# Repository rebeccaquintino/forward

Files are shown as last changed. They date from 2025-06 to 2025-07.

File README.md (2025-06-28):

# Forward Converter

This project implements a **Forward Converter** with three windings, designed for Power Electronics II course in UFSC.

## 📐 Technical Specifications

- **Topology**: Isolated Forward Converter with 3 windings
- **Input (VIN)**: 100V DC
- **Output (VOUT)**: 12.5V DC
- **Switching Device**: IRQ740
- **Diodes**: MUR840
- **Input Capacitor**: 4.7µF @ 250V
- **Output Inductor**: 500µH
- **Transformer**: Handmade three-winding transformer
- **Switching Frequency**: 30k Hz

## 📦 Project Contents

- Electrical schematic (`.SchDoc`)
- PCB layout (`.PcbDoc`)
- Custom libraries (`.SchLib`, `.PcbLib`)
- Draftsman documentation (`.PCBDwf`)

## 🙋‍♀️ Authors

Developed by **Rebecca Quintino do Ó** and **Felipe Pastana**  
As part of the Power Electronics II course – UFSC  
[GitHub Repository](https://github.com/rebeccaquintino/forward)

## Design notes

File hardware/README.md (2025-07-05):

# Forward Converter Hardware Design

This folder contains all the necessary files and documentation related to the hardware design and implementation of the Forward Converter project.

## Folder Structure:

* **`_Previews/`**: Contains various preview images, renderings, or snapshots of the PCB layout, 3D models, or other hardware aspects.
* **`fabrication/`**: Includes all the final files required for manufacturing the Printed Circuit Board (PCB), such as Gerber files, drill files, pick-and-place files, and bill of materials (BOM).
* **`History/`**: Stores previous versions or snapshots of the hardware design files, allowing for tracking changes and reverting to earlier states.
* **`libraries/`**: Contains custom or project-specific component libraries (e.g., Altium libraries for footprints, 3D models, and schematic symbols) used in the PCB design.
* **`outputs/`**: Contains generated output files from the PCB design software, such as PDFs of schematics, assembly drawings, or other production-ready documentation.
* **`source/`**: Holds the primary source files for the hardware design, including the main Altium Designer project files (e.g., schematics and PCB layout).
    * `Forward_Project.PrjPcb`: The main Altium Designer PCB project file.
    * `Forward_Project.PrjPcbStructure`: Related project structure file for Altium Designer.

---

**Note:** This README provides an overview of the hardware design files. For detailed information on the circuit operation, component selection, and design rationale, please refer to the project's main documentation.

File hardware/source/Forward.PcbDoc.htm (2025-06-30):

Reporting Options

# File in Newer Format

Date | : | 29/06/2025
Time | : | 21:51:18
Filename | : | C:\Users\rebec\Desktop\faculdade\optativas\elepot2\forward\hardware\Forward.PcbDoc

Version | Warning
Release 24.4 | CAUTION - This PCB document contains polygon pours with the "Obey Rules" option enabled. If you save the PCB document in this older version, the "Obey Rules" option will be turned off for these polygon pours.

This file was generated by a later version of the software

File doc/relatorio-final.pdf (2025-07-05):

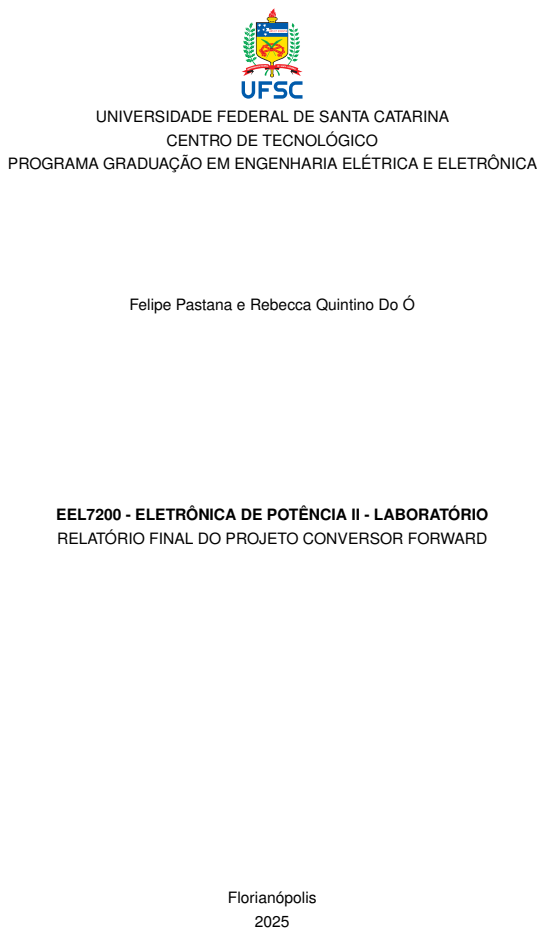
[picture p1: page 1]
Florianópolis

UNIVERSIDADE FEDERAL DE SANTA CATARINA

CENTRO DE TECNOLÓGICO

PROGRAMA GRADUAÇÃO EM ENGENHARIA ELÉTRICA E ELETRÔNICA

Felipe Pastana e Rebecca Quintino Do Ó

EEL7200 - ELETRÔNICA DE POTÊNCIA II - LABORATÓRIO
RELATÓRIO FINAL DO PROJETO CONVERSOR FORWARD

1

### 1 INTRODUÇÃO

Neste trabalho, serão apresentadas as especificações e etapas de projeto teórico e prático para a construção de um conversor do tipo Forward. O trabalho envolve os conhecimentos adquiridos durante toda a disciplina, como cálculos teóricos para a definição dos valores dos componentes, projeto de magnéticos, escolha de componentes, cálculos térmicos, escolha de dissipadores e, por fim, uma análise de perdas e de rendimento do conversor

2

### 2 ESPECIFICAÇÃO DO PROJETO

As especificações do projeto do conversor Forward são apresentadas a seguir:
- Tensão de alimentação da fonte antes do conversor (Vin): 100 V
- Tensão desejada na saída do conversor (Vo): 12,5 V
- Potência desejada na saída do conversor (Po): 50 W
- Frequência de comutação do conversor (fs): 30kHz - 50kHz
- Ondulação da corrente nos indutores (ΔIL
): 0,2%
- Ondulação da tensão em Vo (ΔVo): 0,02%
- Razão cíclica (D): 0,25
- Valor do indutor de saída que suaviza a corrente (L): 5,00E-04 H
- Valor do capacitor de saída que suaviza a tensão (C): 4,70E-06 F
- Relação de espiras dos enrolamentos do transformador: Nprimario= 2 , Nsecundario=

1 e Nterciario= 2

3

### 3 DECISÕES TOMADAS PARA PROJETO

- Foi adotada a frequência de comutação de 50kHz. Conforme foi se tendo uma ideia dos valores de indutância e capacitância, optou-se por uma frequência mais elevada para minimizar o tamanho do indutor a ser construído.

4

### 4 ANÁLISE DO CONVERSOR

O Conversor CC-CC com Transformador (Forward) é um tipo de conversor que utiliza um transformador para fornecer isolamento galvânico entre a entrada e a saída, além de permitir relações de tensão mais flexíveis.

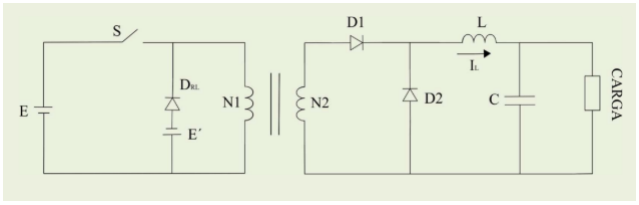
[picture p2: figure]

Figura 1 – Circuito conversor Forward

O circuito do conversor Forward, desconsiderando resistências e indutâncias de dispersão e referindo tudo ao primário, pode ser representado como na Figura 2

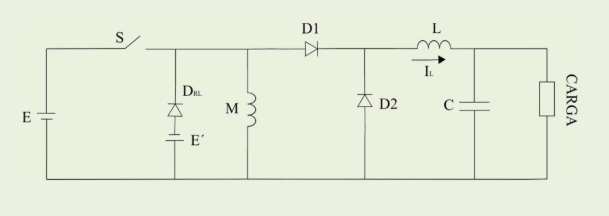
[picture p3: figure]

Figura 2 – Circuito conversor Forward desprezando R e L de dispersão e referindo-se tudo ao primário

Como a corrente de carga (iL
) é aproximadamente constante, o circuito pode ser simplificado como mostrado na Figura 3.

Capítulo 4. ANÁLISE DO CONVERSOR | 5

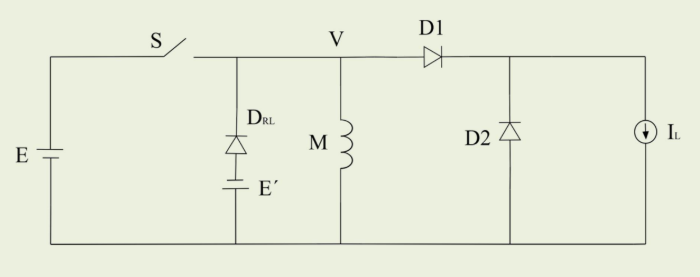
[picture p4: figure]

Figura 3 – Circuito Forward simplificado

O funcionamento do conversor Forward é dividido em duas principais etapas:

- 1ª ETAPA Nesta etapa, a chave S está fechada. Parte da energia cedida pela fonte E é transferida para a carga e outra parte é acumulada da indução magnética. Durante este período, os diodos D3 e D2 estão bloqueados.
- 2ª ETAPA Quando a chave S abre, o transformador deve ser desmagnetizado a cada ciclo para evitar saturação. A corrente iM deve ser anulada durante o tempo de abertura de S. Nos conversores práticos a desmagnetização é realizada por um enrolamento auxiliar, como apresentado na Figura 4. A condição para desmagnetização é dada pela relação entre o tempo de fechamento (t
f

) e o tempo de abertura (ta) da chave: E

′
E

=

tf
ta

. A tensão

máxima sobre a chave S é Vs = E + E

′ = E(1 + DMAX
1–DMAX

).

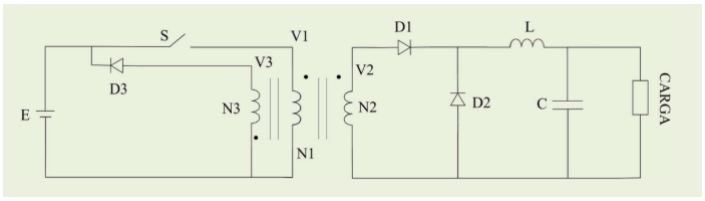
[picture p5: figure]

Figura 4 – Circuito do conversor Forward com enrolamento auxilair

6

### 5 CÁLCULO DOS COMPONENTES DE SAÍDA

5.1 CÁLCULO DA INDUTÂNCIA DE SAÍDA

Para o projeto do conversor Forward, a indutância de saída (L) é um componente usado para suavizar a corrente na carga e garantir o modo de condução contínua. O valor da ondulação de corrente no indutor é um parâmetro para o dimensionamento. Primeiramente, a corrente média de saída (Io) é um valor medido a partir das especificações de potência e tensão de saída. Para o nosso projeto, temos:

Io = 3,95 A

A ondulação de corrente máxima permitida no indutor (ΔIL

) é calculada como
uma porcentagem da corrente de entrada nominal (conforme especificado na seção de especificações). No entanto, para o indutor de saída de um conversor Forward, a ondulação é frequentemente relacionada à corrente de saída para garantir o MCC. Como a tensão de entrada é de 100V e a potência de saída é de 50W, a corrente de entrada (I

in) pode ser calculada como:.

I
in =

Po
Vin

(1)

Substituindo os valores temos que:

I

in = 0,50 A

A ondulação de corrente no indutor L (ΔIL

) é a dada pela expressão:

ΔIL = ΔIL% × I
in

ΔIL = 0,2 × 0,50 A

ΔIL = 0,10 A

A expressão para o cálculo da indutância de saída para um conversor tipo Buck (cuja etapa de saída é similar à do Forward) pode ser adaptada:

ΔImax =

E
4 · L · f

(2)

Rearranjando essa equação para encontrar L:

L =

E
4 · ΔImax · f

(3)

Capítulo 5. CÁLCULO DOS COMPONENTES DE SAÍDA | 7

Aplicando os valores do nosso projeto para a etapa de saída (onde a tensão E seria a tensão refletida do primário no secundário, ou Vo para um Forward ideal), e considerando a tensão de entrada Vin refletida para o secundário e a razão cíclica D, podemos usar a seguinte adaptação para L, considerando Vin como a tensão aplicada ao primário e a ondulação máxima no indutor:

L =

Vin · D fs · ΔIL | (4)

Utilizando os valores do projeto: Vin = 100 V D = 0,25 fs = 50k Hz ΔIL = 0,10 A

L =

100 · 0,25
50.000 · 0,10 | (5)
L = 0,005H = 500 μH | (6)

O valor do indutor de saída (L) para suavizar a corrente foi especificado como 500 · 10⁻⁶ H (ou 500μH).

5.2 CÁLCULO DA CAPACITÂNCIA DE SAÍDA

Para o cálculo da capacitância de saída (C), que suaviza a tensão na saída do conversor, é necessário considerar a ondulação máxima de tensão permitida (ΔVo). A ondulação de tensão de saída (ΔVo) é calculada como:

ΔVo = ΔVo% × Vo | (7)

Considerando a ondulação de 0,2

ΔVo = 0,02 × 12,5

ΔVo = 0,25 V

No entanto, a ondulação da tensão na saída (ΔVo) foi especificada como 0,25 V. Utilizaremos este valor especificado para os cálculos de dimensionamento, pois ele reflete a meta de projeto para a ondulação de tensão.
A ondulação da tensão no capacitor C de saída para um conversor tipo Buck (e aplicável ao Forward) é dada pela expressão:

ΔVCmax =

Io 8 × fs × C | (8)

Rearranjando essa equação para encontrar C:

C =

Io 8 × fs × ΔVCmax | (9)

Utilizando os valores do projeto: Io = 3,95 A fs = 50.000 Hz ΔVo = 0,25 V

Capítulo 5. CÁLCULO DOS COMPONENTES DE SAÍDA | 8

Substituindo os valores na equação para C:

C =

3,95
8 × 50.000 × 0,25

C = 3,95 × 10⁻⁵ F = 39,5 µF

O valor do capacitor de saída (C) escolhido é uma aproximação do resultado para um valor comercial de 4,70 · 10⁻⁶ F (ou 4,7 µF).

9

### 6 SIMULAÇÃO

A simulação apresentada a seguir foi realizada com carga nominal. Alguns parâmetros dos diodos, do MOSFET e do Transformador que o modelo do componente no PSIM fornece para simular as não idealidades, também foram utilizados. O circuito estudado está representado na Figura 5 abaixo.

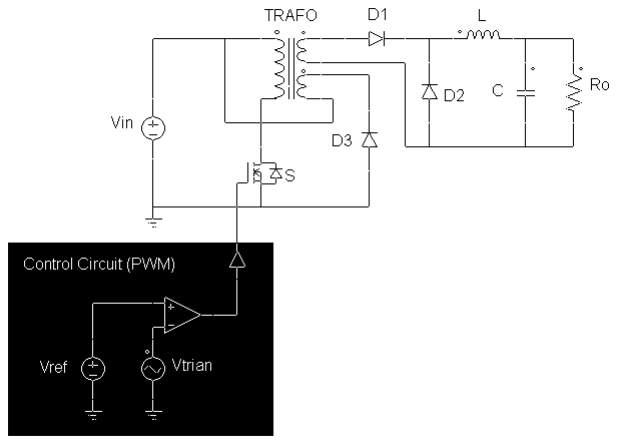
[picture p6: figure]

Figura 5 – Circuito de simulação do Forward

Importante ressaltar que os valores utilizados na simulação são correspondentes aos dos componentes utilizados no projeto do conversor. Foram consultados os datasheets e, quando cabível, realizadas correções com fatores retirados das tabelas apresentadas no documento do componente.
A lista a seguir determina os parâmetros da simulação do circuito da Fig.3:
- Vin: Fonte de entrada de 100 V.
- Vo: Tensão de saída esperada de 12,5 V.
- Po: Potência nominal de saída de 50 W.
- D: Razão cíclica de 0,25.
- fs: Frequência de comutação escolhido foi de 50 kHz.
- delta_IL: Ondulação de corrente de 0.2%.

Capítulo 6. SIMULAÇÃO | 10
- delta_Vo: Ondulação de tensão de 0.02%.
- L: Indutância do indutor construído de 500 μH.
- C: Capacitância de 47 μF.
- Trafo: Foram estabelecidos alguns parâmetros relacionados ao Transformador de 3 enrolamentos construído. Dentre eles estão:

– Rp: Resistência primária do transformador de 100 pΩ.

– Rs: Resistência secundária do transformador de 100 pΩ.

– Rt: Resistência terciária do transformador de 100 pΩ.

– Lp: Indutância primária do transformador de 1 μH.

– Ls: Indutância secundária do transformador de 1 μH.

– Lt: Indutância terciária do transformador de 1 μH.

– Lm: Indutância de magnetização do transformador de 400 μH.

– Trafo Np: Número de espiras do primário do transformador é 2.

– Trafo Ns: Número de espiras do secundário do transformador é 1.

– Trafo Nt: Número de espiras do terciário do transformador é 2.

- PWM: Para simular o circuito de comando foram estabelecidos alguns parâmetros. Dentre eles estão:

– Vref: Tensão de referência com amplitude de 1 V

– Vtrian: Tensão da onda triangular com valor de pico a pico de 0,25V

- D: Diodo, cujo parâmetro "Diode Threshold Voltage"foi ajustado com o valor 1,00 V. Este parâmetro corresponde à queda de tensão no diodo quando ele conduz.
- S: Interruptor MOSFET. O parâmetro "On Resistance"foi ajustado para 2,00× 0,55 Ω. 2,00 é o fator de correção correspondente da resistência de dreno-fonte devido a temperatura da junção, estimada, operar em 120◦C. E 0,55 Ω é a resistência dreno-fonte a temperatura ambiente de 25◦C.

As perdas de comutação do interruptor e do diodo não foram inseridas na simulação. O rendimento por simulação verificado foi de, aproximadamente, 95%.

6.1 FORMAS DE ONDA

A seguir, as formas de onda por simulação do conversor boost projetado. Os nomes em cada imagem são referentes à Figura 5.

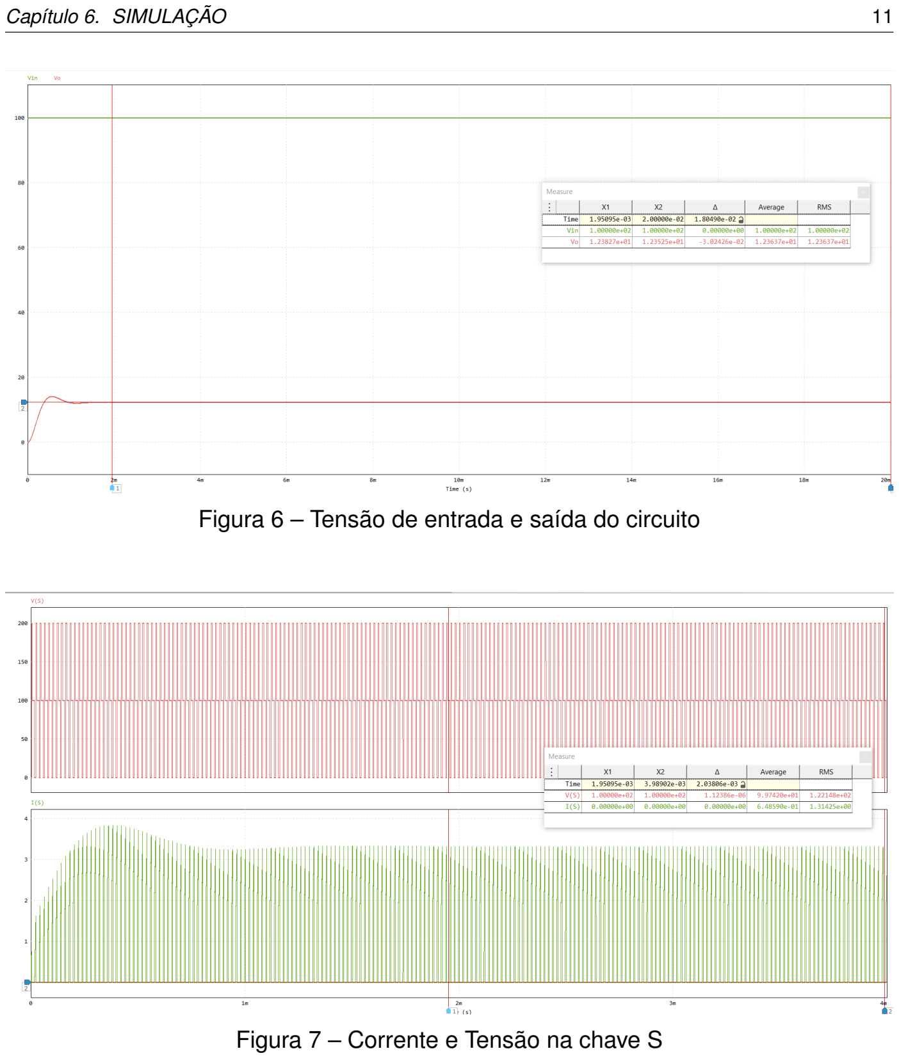
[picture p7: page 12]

Capítulo 6. SIMULAÇÃO | 11

Figura 6 – Tensão de entrada e saída do circuito

Figura 7 – Corrente e Tensão na chave S

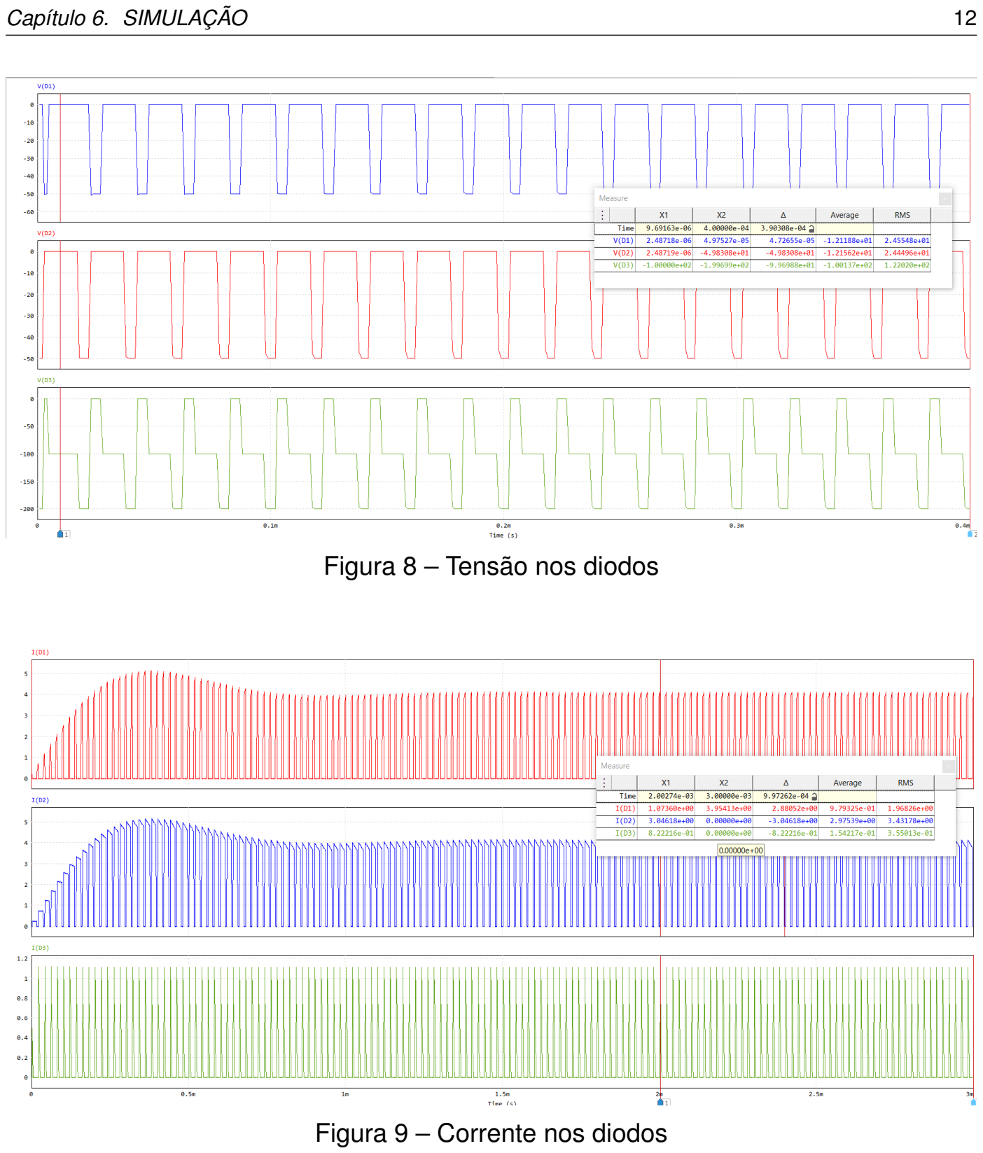
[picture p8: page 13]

Capítulo 6. SIMULAÇÃO | 12

Figura 8 – Tensão nos diodos

Figura 9 – Corrente nos diodos

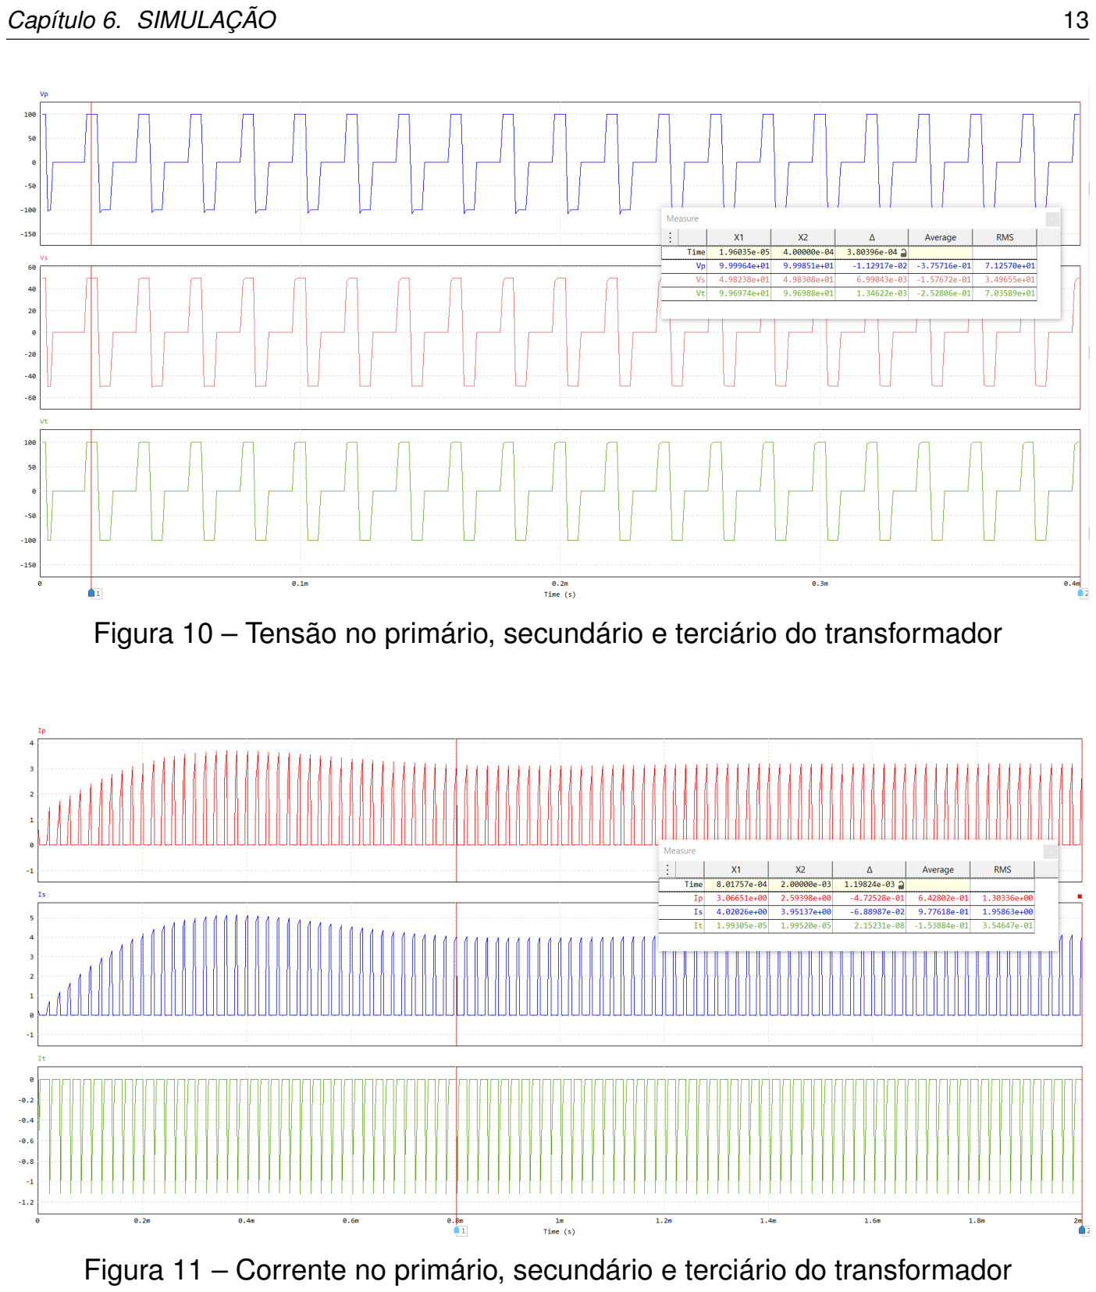
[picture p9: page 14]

Capítulo 6. SIMULAÇÃO | 13

Figura 10 – Tensão no primário, secundário e terciário do transformador

Figura 11 – Corrente no primário, secundário e terciário do transformador

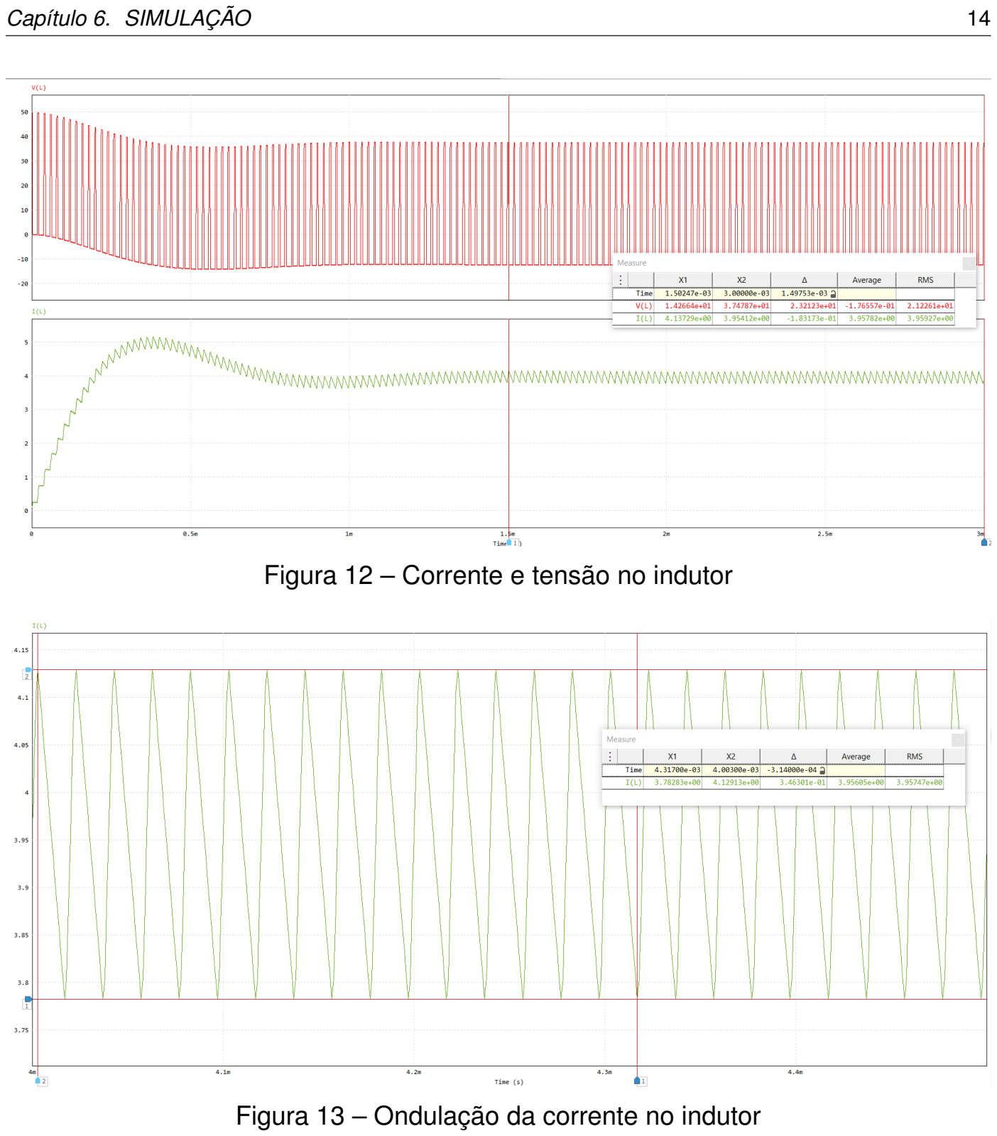
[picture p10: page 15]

Capítulo 6. SIMULAÇÃO | 14

Figura 12 – Corrente e tensão no indutor

Figura 13 – Ondulação da corrente no indutor

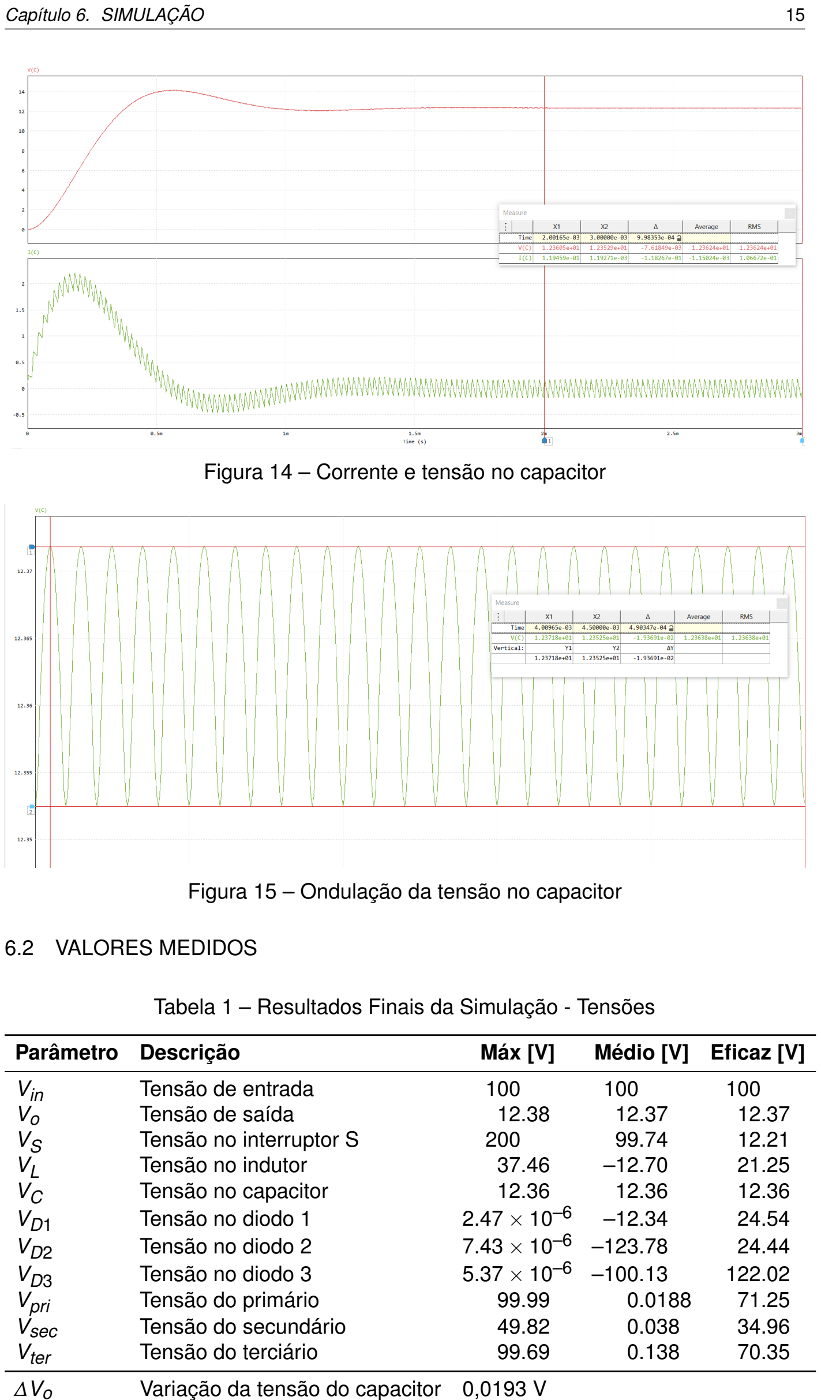
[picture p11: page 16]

Capítulo 6. SIMULAÇÃO | 15

Figura 14 – Corrente e tensão no capacitor

Figura 15 – Ondulação da tensão no capacitor

6.2 VALORES MEDIDOS

Tabela 1 – Resultados Finais da Simulação - Tensões

Parâmetro Descrição | Máx [V] | Médio [V] Eficaz [V]
Vin | Tensão de entrada | 100 | 100 | 100
Vo | Tensão de saída | 12.38 | 12.37 | 12.37
VS | Tensão no interruptor S | 200 | 99.74 | 12.21
VL | Tensão no indutor | 37.46 | –12.70 | 21.25
VC | Tensão no capacitor | 12.36 | 12.36 | 12.36
VD1 | Tensão no diodo 1 | 2.47 × 10⁻⁶ | –12.34 | 24.54
VD2 | Tensão no diodo 2 | 7.43 × 10⁻⁶ –123.78 | 24.44
VD3 | Tensão no diodo 3 | 5.37 × 10⁻⁶ –100.13 | 122.02
Vpri | Tensão do primário | 99.99 | 0.0188 | 71.25
Vsec | Tensão do secundário | 49.82 | 0.038 | 34.96
Vter | Tensão do terciário | 99.69 | 0.138 | 70.35
ΔVo | Variação da tensão do capacitor 0,0193 V

Capítulo 6. SIMULAÇÃO | 16

Tabela 2 – Resultados Finais da Simulação - Correntes

Parâmetro Descrição | Máx [A] | Médio [A] Eficaz [A]
IS | Corrente no interruptor S | 3.34 | 0.649 | 1.31
IL | Corrente no Indutor L | 4.00 | 3.96 | 3.96
IC | Corrente no capacitor C | 0.16 | –0.0014 | 0.10
ID1 | Corrente do diodo 1 | 4.12 | 0.979 | 1.98
ID2 | Corrente do diodo 2 | 4.14 | 2.97 | 3.43
ID3 | Corrente do diodo 3 | 1.1 | 0.154 | 0.355
Ipri | Corrente no primário | 3.06 | 0.642 | 1.30
Isec | Corrente no secundário | 4.02 | 0.977 | 1.95
I
ter | Corrente no terciário | 9.97 × 10⁻⁶ | –0.153 | 0.354
ΔIL | Variação da corrente do indutor 3,95 A

17

### 7 ESFORÇOS DE TENSÃO E CORRENTE

Para o dimensionamento adequado dos componentes semicondutores e magnéticos de um conversor, é fundamental determinar os esforços de tensão e corrente máximos e eficazes a que eles serão submetidos. Esses valores servem como base para a escolha dos componentes, garantindo margens de segurança adequadas. Recomendase adotar margens típicas de 20% a 30% sobre os valores calculados para garantir a robustez do projeto.
Os transitórios rápidos (como os de comutação e sobretensões) são inevitáveis e devem ser controlados e mitigados através de técnicas como snubbers (RC, RCD), diodos de flyback, e clamp magnético, permanecendo dentro dos limites transitórios especificados nos datasheets.
A seguir, são apresentados os cálculos dos principais esforços de tensão e corrente para os componentes do conversor Forward, baseados nas formas de onda e equações fornecidas.

7.1 DADOS DE PROJETO PARA CÁLCULO DE ESFORÇOS

Utilizaremos os seguintes valores do projeto:
- Tensão de entrada (Vin): 100 V
- Razão cíclica (D): 0,25
- Corrente média de saída (Iout ou Io): 3,95 A
- Número de espiras do primário (NP): 2
- Número de espiras do secundário (NS): 1
- Número de espiras do enrolamento de desmagnetização (NT ): 2
- Ondulação de corrente no indutor de saída (ΔIL
): 0,10 A
- Frequência de comutação (fs): 50.000 Hz
- Período de comutação (T = 1/fs): 1/50.000 = 20 µs
- Indutância de magnetização (Lm): 400 µH
A relação de espiras n1

(primário para secundário) é n1 = NP/NS = 2/1 = 2. Primeiramente, calculamos a ondulação da corrente de magnetização (ΔiLm):

ΔiLm =

vinDT
Lm

(10)

ΔiLm =

100 V · 0,25 · (20 · 10⁻⁶ s) 400 · 10⁻⁶ H

ΔiLm =

0,0005
400 · 10⁻⁶ = 1,25 A

Capítulo 7. ESFORÇOS DE TENSÃO E CORRENTE | 18

7.2 ESFORÇOS NA CHAVE (MOSFETS)

- Tensão Máxima na Chave (VSmax ):

VSmax =

NP
NT

+ 1
vin | (11)

VSmax =

2
2

+ 1
- 100 V = (1 + 1) · 100 V = 200 V
- Corrente Máxima na Chave (ISmax ):

ISmax =

NS
NP
- ID1max + ΔiLm | (12)

Onde ID1max é a corrente máxima no diodo D1, que é Iout +

ΔiL
2

ID1max = 3,95 A + 0,10 A
2

= 3,95 A + 0,05 A = 4,00 A

Então,

ISmax =

1
2
- 4,00 A + 1,25 A = 2,00 A + 1,25 A = 3,25 A
- Corrente Média na Chave (ISmedio):

ISmedio =

Io
n1
D | (13)

ISmedio =

3,95 A
2
- 0,25 = 1,975 A · 0,25 = 0,49375 A
- Corrente RMS na Chave (ISrms):

ISrms =

Io

√
D
n1

(14)

ISrms =

3,95 A√
0,25
2

=

3,95 A · 0,5
2

=

1,975 A
2

= 0,9875 A

7.3 ESFORÇOS NO DIODO D1 (DIODO RETIFICADOR)

- Tensão Máxima no Diodo D1 (VD1max ):

VD1max =

NS
NT
vin | (15)

VD1max =

1
2
- 100 V = 50 V

Capítulo 7. ESFORÇOS DE TENSÃO E CORRENTE | 19
- Corrente Máxima no Diodo D1 (ID1max ):

ID1max = Iout +

ΔiL
2 | (16)

ID1max = 3,95 A + 0,10 A
2

= 3,95 A + 0,05 A = 4,00 A

- Corrente Média no Diodo D1 (ID1 ):
ID1 = DIO | (17)

ID1 = 0,25 · 3,95 A = 0,9875 A

- Corrente RMS no Diodo D1 (ID1rms):

ID1rms = IO

√
D | (18)

ID1rms = 3,95 Ap
0,25 = 3,95 A · 0,5 = 1,975 A

7.4 ESFORÇOS NO DIODO D2 (DIODO DE RODA LIVRE)

- Tensão Máxima no Diodo D2 (VD2max ):

VD2max =

NS
NP
vin | (19)

VD2max =

1
2
- 100 V = 50 V
- Corrente Média no Diodo D2 (ID2 ):
ID2 = (1 – D)IO | (20)

ID2 = (1 – 0,25) · 3,95 A = 0,75 · 3,95 A = 2,9625 A

- Corrente RMS no Diodo D2 (ID2rms):

ID2rms = IO

√
1 – D | (21)

ID2rms = 3,95 Ap

1 – 0,25 = 3,95 Ap
0,75 ≈ 3,95 A · 0,866 = 3,4237 A

7.5 ESFORÇOS NO DIODO D3 (DIODO DE DESMAGNETIZAÇÃO)

- Tensão Máxima no Diodo D3 (VD3max ):

VD3max =

NT
NP

+ 1
vin | (22)

VD3max =

2
2

+ 1
- 100 V = (1 + 1) · 100 V = 200 V
- Corrente Máxima no Diodo D3 (ID3max ):

ID3max =

NP
NT
ΔiLm | (23)

ID3max =

2
2
- 1,25 A = 1 · 1,25 A = 1,25 A

Capítulo 7. ESFORÇOS DE TENSÃO E CORRENTE | 20

7.6 ESFORÇOS NO INDUTOR DE SAÍDA (L)

- Corrente RMS no Indutor (ILrms): Para um indutor operando em modo de condução contínua (MCC) com ondulação de corrente, a corrente RMS é aproximadamente igual à corrente média de saída, especialmente se a ondulação for pequena.
ILrms ≈ IO | (24)

ILrms ≈ 3,95 A

7.7 ESFORÇOS NO CAPACITOR DE SAÍDA (C)

- Corrente RMS no Capacitor (ICrms): A corrente RMS no capacitor é determinada pela ondulação de corrente no indutor.

ICrms =

Δi
√

L
12

(25)

ICrms =

0,10 A
√
12

≈

0,10
3,464

≈ 0,0289 A

7.8 RESULTADOS DOS ESFORÇOS CALCULADOS

A Tabela 3 e a Tabela 4 resumem os esforços de tensão e corrente calculados para os componentes do conversor Forward.

Tabela 3 – Esforços de Tensão Calculados no Conversor Forward

Componente Parâmetro | Valor Calculado [V]
MOSFET | Tensão Máx. (VSmax ) | 200
Diodo D1 | Tensão Máx. (VD1max ) | 50
Diodo D2 | Tensão Máx. (VD2max ) | 50
Diodo D3 | Tensão Máx. (VD3max ) | 200

Capítulo 7. ESFORÇOS DE TENSÃO E CORRENTE | 21

Tabela 4 – Esforços de Corrente Calculados no Conversor Forward

Componente Parâmetro | Valor Calculado [A]
MOSFET | Corrente Máx. (ISmax ) | 3.25
| Corrente Média (ISmedio) | 0.4938
| Corrente RMS (ISrms) | 0.9875
Diodo D1 | Corrente Máx. (ID1max ) | 4.00
| Corrente Média (ID1
| ) | 0.9875
| Corrente RMS (ID1rms) | 1.975
Diodo D2 | Corrente Média (ID2
| ) | 2.9625
| Corrente RMS (ID2rms) | 3.4237
Diodo D3 | Corrente Máx. (ID3max ) | 1.25
Indutor (L) | Corrente RMS (ILrms) | 3.95
Capacitor (C) | Corrente RMS (ICrms) | 0.0289

22

### 8 ESCOLHA DO INTERRUPTOR

A escolha dos componentes para uso no projeto deve atender a alguns critérios práticos. Em situações reais, indutâncias e capacitâncias parasitas causam ressonâncias indesejadas no circuito. O conhecimento prévio desse aspecto possibilita o dimensionamento correto dos dispositivos. Nenhuma técnica de comutação suave foi empregada no conversor, o que possibilitaria reduzir as sobretensões e trabalhar com componentes mais próximos dos parâmetros calculados. Desta forma, os componentes são submetidos a sobretensões elevadas, e isso será levado em conta na determinação do dispositivo.
Considerando os valores de esforços de tensão e corrente calculados na Tabela 3 e Tabela 4, o interruptor deverá suportar uma tensão superior à máxima tensão de pico na chave (VSmax = 200 V). A corrente é um parâmetro que pode ser trabalhado mais próximo do calculado, pois o que limita é a capacidade térmica do material. Deste modo, o transistor escolhido foi o IRF740.
A página inicial do datasheet do IRF740 (Figura 16) mostra que sua tensão máxima dreno-fonte (VDS) é de 400 V, o que é superior aos 200 V calculados para VSmax , garantindo uma boa margem de segurança. A corrente de dreno contínua (ID) para TC = 25◦C é de 10 A e para TC = 100◦C é de 6.3 A, o que atende à corrente

máxima calculada de ISmax = 3,25 A.
Para o cálculo de perdas e análises térmicas, o parâmetro "On Resistance"(RDS(on) )
a 25◦C para VGS = 10 V é de 0,55 Ω. O fator de correção da resistência de dreno-fonte devido à temperatura da junção, estimada em 120◦C, pode ser obtido da Figura 17 do

datasheet do IRF740 ("Normalized On-Resistance vs. Temperature") e é de aproximadamente 2,0.

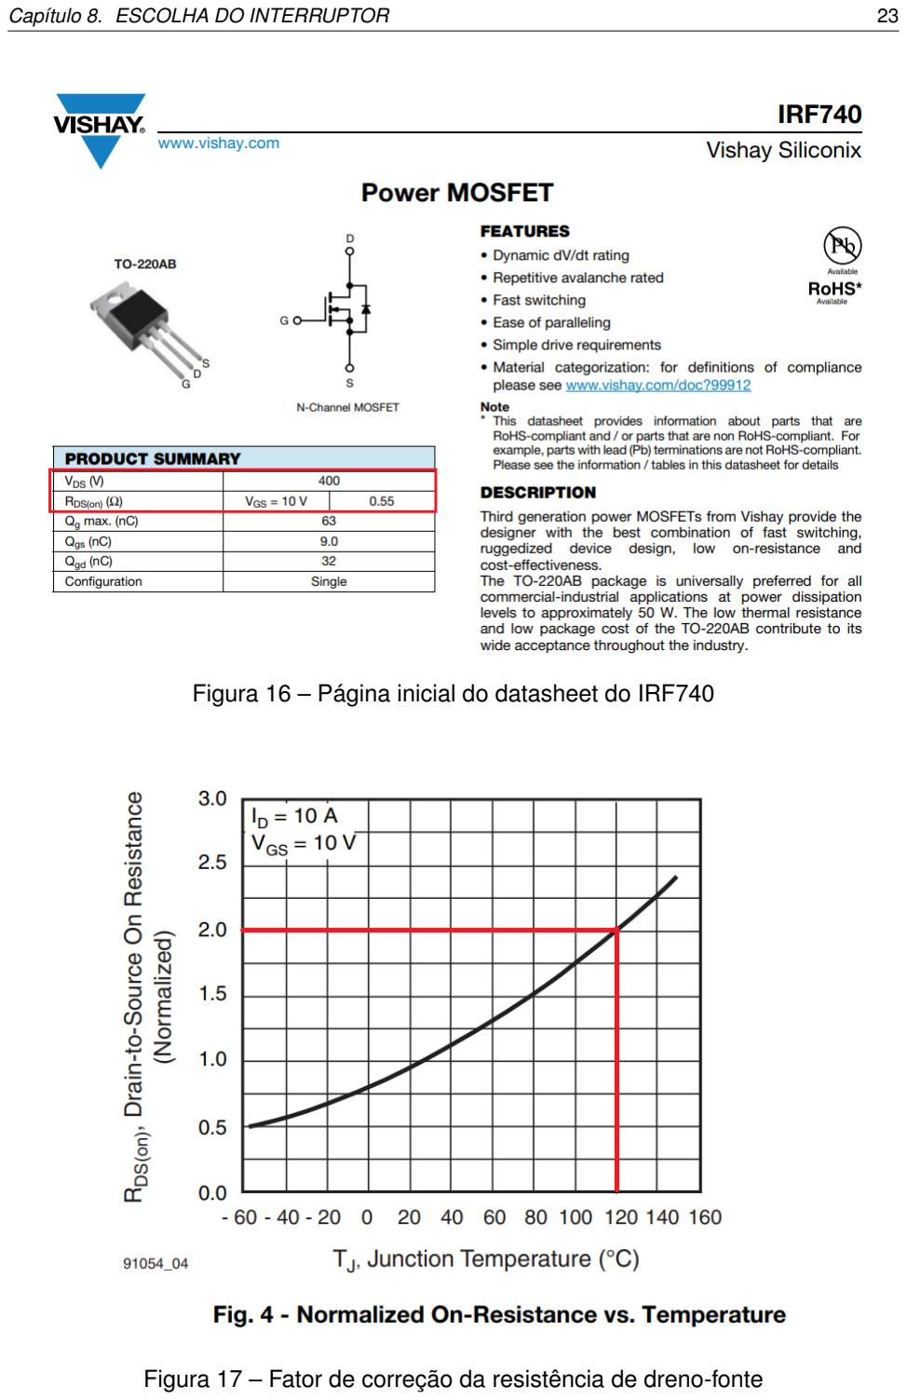
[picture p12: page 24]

Capítulo 8. ESCOLHA DO INTERRUPTOR | 23

Figura 16 – Página inicial do datasheet do IRF740

Figura 17 – Fator de correção da resistência de dreno-fonte

24

### 9 ESCOLHA DOS DIODOS

Os diodos do conversor Forward (D1, D2 e D3) escolhidos para o projeto foram o MUR840. A Figura 18 mostra o datasheet do MUR840 com algumas especificações.

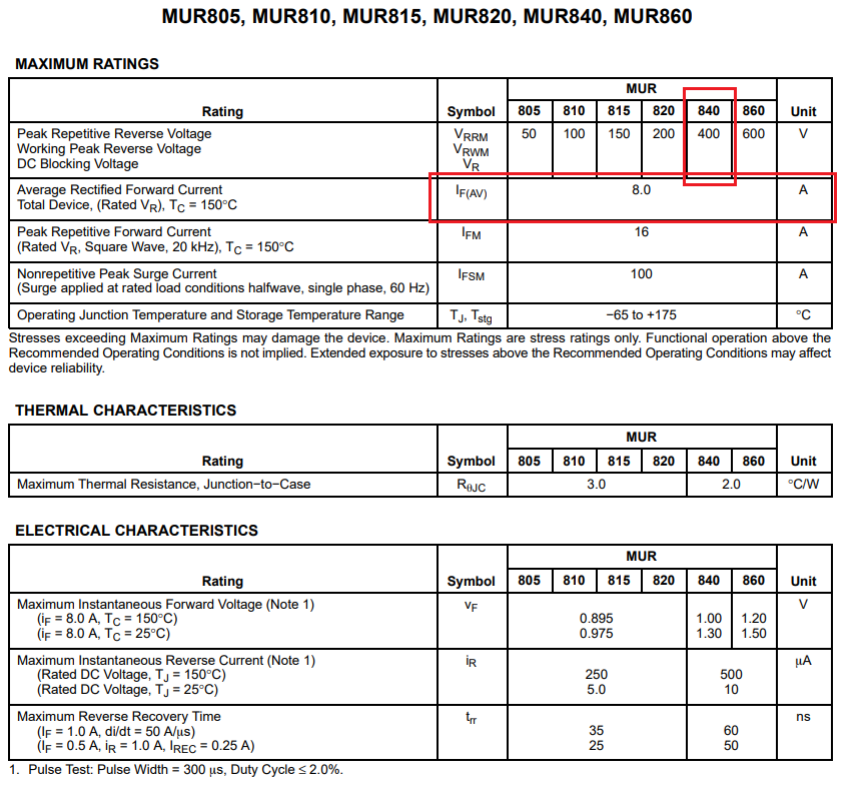
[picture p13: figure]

Figura 18 – MUR840 datasheet

Os requisitos para a escolha dos diodos incluem a tensão máxima sobre o diodo, a frequência de comutação, e os valores eficaz e médio da corrente no diodo.

- Diodo D1 (Retificador): A tensão máxima (VD1max ) calculada foi de 50 V. O MUR840 suporta uma tensão reversa de 400 V (para o modelo MUR840), superando o valor calculado. A corrente máxima calculada (ID1max ) foi de 4,00 A, e a corrente média (ID1

) foi de 0,9875 A. O MUR840 possui uma corrente média retificada de 8.0 A para TC = 150◦C, o que atende confortavelmente

aos requisitos de corrente. O parâmetro "Diode Threshold Voltage"(VF ) para o MUR840 a IF = 8.0 A e TC = 150◦C é de 1,00 V.

Capítulo 9. ESCOLHA DOS DIODOS | 25
- Diodo D2 (Roda Livre): A tensão máxima (VD2max ) calculada foi de 50 V. O MUR840 também atende a esse requisito de tensão (400 V). A corrente média calculada (ID2

) foi de 2,9625 A e a corrente RMS (ID2rms) foi de 3,4237
A. A capacidade de corrente do MUR840 (8.0 A média) é suficiente.
- Diodo D3 (Desmagnetização): A tensão máxima (VD3max ) calculada foi de 200 V. O MUR840 (400 V) atende a esse requisito. A corrente máxima calculada (ID3max ) foi de 1,25 A, também dentro da capacidade do diodo.

26

### 10 CIRCUITO DE COMANDO

Para o acionamento do interruptor (MOSFET IRF740) foi utilizada uma PCI com o CI dedicado UC3525. Este circuito integrado possui internamente circuitos osciladores e comparadores necessários para o acionamento da chave.

10.1 REGULAÇÃO DA FREQUÊNCIA

A frequência do pulso do comando que irá acionar a chave é definida pelo capacitor CT e pelo resistor RT de acordo com a seguinte expressão:

f =

1
CT (0,7RT )

(26)

Considerando uma frequência de chaveamento fs = 50kHz para o UC3525, podemos rearanjar a Equação (26) para encontrar o produto CT RT :

CT RT =

1
fs · 0,7 =

1
50000 · 0,7 | 15
CT RT = 2,857 × 10⁻⁵ s | (27)

Admitir-se-á CT igual a 5,00nF, então tem-se:

CT = 5,00nF | (28)

Com esse valor de CT , podemos calcular RT :

RT =

2,857 × 10⁻⁵
5,00 × 10⁻⁹ = 5,714kΩ | (29)

10.2 REGULAÇÃO DA RAZÃO CÍCLICA

A razão cíclica pode ser definida através dos resistores R1
, R2 e R3
| . A tensão de
referência do CI (UC3525) pode ser obtida no datasheet e tem valor de 5,1V. Através dos valores máximo e mínimo da onda triangular portadora gerada pelo CI, pode-se calcular a razão cíclica pela seguinte equação:

Vportmax

= 2,9V | (30)
Vportmin = 0,86V | (31)

A corrente I no divisor de tensão é dada por:

I =

Vref Rtot
=
5,1 Rtot | 22

Onde Rtot é a soma dos resistores R1 e R3 :

Rtot = R1 + R3 | (32)

Capítulo 10. CIRCUITO DE COMANDO | 27

A tensão de referência pode ser expressa em termos da razão cíclica (D), dos níveis da portadora e da queda de tensão em R1
:

Vref = Vportmin + D(Vportmax

– Vportmin ) + R1

I | (33)

Desse modo, com os valores propostos:

R1 = 17Ω | (34)
R3 = 10Ω | (35)

10.3 CÁLCULO DO RESISTOR DE GATE (RG)

O resistor de gate (RG) é utilizado para controlar a taxa de variação da tensão no gate do MOSFET, influenciando os tempos de chaveamento tr (tempo de subida) e t
f

(tempo de descida). Para o cálculo de RG, utiliza-se a seguinte expressão:

RG =

t
f 2,2 · Ciss | (36)

Utilizando os dados do MOSFET IRF740 fornecidos na Figura 19, temos:
- Tempo de queda t

f = 2,4 × 10⁻⁸ s

- Capacitância de entrada CISS = 1,4 × 10⁻⁹ F

Substituindo os valores na Equação (36):

RG =

2,4 × 10⁻⁸ s
2,2 · (1,4 × 10⁻⁹ F)

RG =

2,4 × 10⁻⁸
3,3 × 10⁻⁹

RG ≈ 7,27Ω

Portanto, o valor do resistor de gate RG será de aproximadamente 7,3Ω.

RG = 7,3Ω | (37)

Capítulo 10. CIRCUITO DE COMANDO | 28

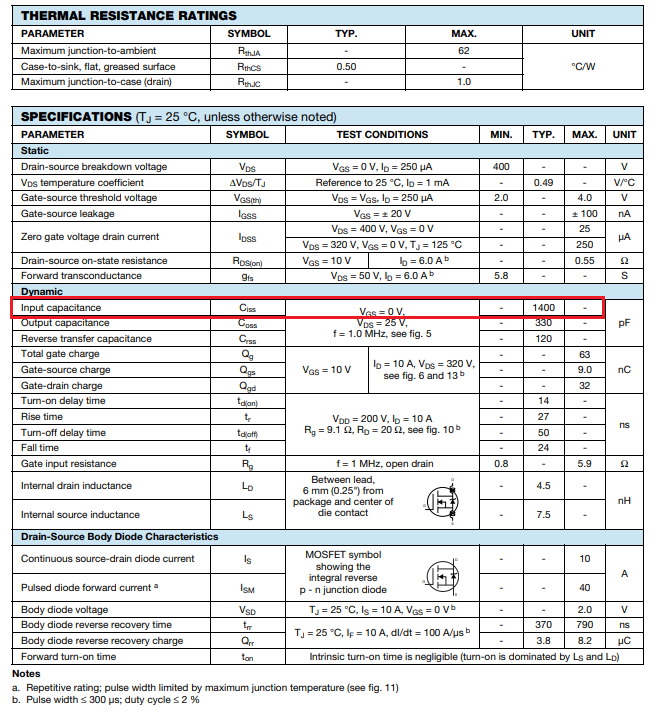
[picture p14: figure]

Figura 19 – Valor de CISS no datasheet do IRF740

29

### 11 PROJETO DO INDUTOR

Com o valor da indutância determinada de acordo com a equação (5), adotou-se o valor de 500μH para o projeto do indutor e as especificações da tabela abaixo.

Tabela 5 – Especificações do Indutor

Indutância | L = 500μH
Corrente máxima (ILpico) | Ip = 4,00A
Corrente Eficaz (ILef) | Irms = 3,96A
Ondulação de corrente (ΔIL ) | ΔIL = 0,346A
Fluxo máximo (Bm) | Bm = 0,3T
Densidade Máxima de corrente (Jm) | Jm = 600 A cm²
Fator de utilização da janela (Kw ) | Kw = 0,8
Frequência (fs) | f = 50kHz

Para o projeto do indutor, foi usada uma planilha para o cálculo de parâmetros necessários para a construção do indutor pelos membros da equipe. Esta planilha foi fornecida pelos professores da disciplina durante o andamento das fases do projeto. Destaca-se no projeto o uso de uma frequência considerada alta, a fim de reduzir as dimensões do indutor, usando um núcleo menor, conseguindo uma maior densidade de potência para o conversor estudado. Como parâmetros de saída da planilha de projeto, obteve-se os seguintes resultados:

Tabela 6 – Resultados Obtidos no Projeto do Indutor

Núcleo escolhido | NEE-30/14
Fabricante | Thornton
Material | IP12R
Número de espiras (N) | 56
Bitola do condutor | 22 AWG
Condutores em paralelo (ncond ) | 2
Comprimento de cada condutor (lfio) | 3,85m
Perdas no cobre (Pcobre) | 1,58W
Perdas no núcleo (Pnucleo) | 0,0009268W
Elevação de temperatura (ΔT) | 44,69◦C

A seguir, são detalhados os cálculos e escolhas para cada etapa do projeto do indutor.

11.1 ESCOLHA DO NÚCLEO

O primeiro passo no projeto do indutor é a escolha do núcleo, que é feita através do produto das áreas AeAw . A expressão para este produto é dada por:

Ae × Aw =

L × ILpico × ILef

Bmax × Jmax × Kw

× 10⁴
(38)

Capítulo 11. PROJETO DO INDUTOR | 30

Onde:
- L = 500μH
- ILpico = 4,00A
- ILef = 3,96A
- Bmax = 0,3T
- Jmax = 600A/cm²
- Kw = 0,8
Substituindo os valores na Equação 1:

Ae × Aw =

500 × 10⁻⁶ × 4,00 × 3,96
0,3 × 600 × 0,8 × 10⁴

Ae × Aw =

0,00792
144 × 10⁴

Ae × Aw ≈ 0,000055 × 10⁴

cm⁴

Ae × Aw ≈ 0,5500 cm⁴

Com base no valor calculado de AeAw ≈ 0,5500 cm⁴
, e consultando a Tabela de núcleos de ferrite tipo EE (Thornton) presente na documentação, o núcleo escolhido foi o Equação NEE-30/14Equação que possui AeAw = 1,02 cm⁴
, sendo o mais próximo e
adequado para o projeto. As dimensões do núcleo NEE-30/14 são:
- Área da seção transversal do núcleo (Ae) = 1,2 cm²
- Área da seção transversal da janela (Aw ) = 0,85 cm²
- Comprimento médio de uma espira (lme) = 6,7 cm
- Volume do núcleo (Vnucleo) = 8,00 cm³

11.2 CÁLCULO DO NÚMERO DE ESPIRAS (N)

O número de espiras é um parâmetro crítico no projeto do indutor. A fórmula para o cálculo do número de espiras é dada por:

N = L ×

ILpico

Bmax × Ae

× 10⁴
(39)

Onde:
- L = 500μH
- ILpico = 4,00A
- Bmax = 0,3T
- Ae = 1,2 cm²
(do núcleo escolhido)

Capítulo 11. PROJETO DO INDUTOR | 31

Substituindo os valores na Equação 2:

N = 500 × 10⁻⁶ ×

4,00
0,3 × 1,2 × 10⁻⁴ × 10⁴

N = 500 × 10⁻⁶ ×

4,00
3,6 × 10⁻⁵
N = 500 × 10⁻⁶ × 111111,11

N ≈ 55,56 espiras

Considerando o arredondamento para o número inteiro superior, o número de espiras adotado é N = 56 voltas, conforme indicado nos resultados da planilha.

11.3 CÁLCULO DO ENTREFERRO (lentreferro)

A adição de um entreferro é crucial para evitar a saturação do núcleo e para estabilizar a indutância em função da temperatura e do ponto de operação. O comprimento do entreferro é calculado por:

lentreferro =

N

2 × μ0 × Ae
L
× 10⁻² [cm] | (40)

Onde:
- N = 56 espiras
- μ0 = 4π × 10⁻⁷ H/m (permeabilidade magnética do vácuo)
- Ae = 1,2 cm² = 1,2 × 10⁻⁴ m²
- L = 500μH = 500 × 10⁻⁶ H

Substituindo os valores na Equação 3:

lentreferro =

56² × (4π × 10⁻⁷) × (1,2 × 10⁻⁴)
500 × 10⁻⁶ | × 10⁻²

lentreferro =

3136 × 1,508 × 10⁻¹⁰
500 × 10⁻⁶ × 10⁻²

lentreferro =

4,729 × 10⁻⁷
500 × 10⁻⁶ × 10⁻²

lentreferro ≈ 0,0009458 × 10⁻² m

lentreferro ≈ 0,09458 cm

O valor calculado para o entreferro é de aproximadamente 0,0946 cm. Os resultados da planilha indicam um entreferro de 0,0946 cm, o que mostra boa concordância.

11.4 CÁLCULO DA BITOLA DO CONDUTOR E NÚMERO DE FIOS EM PARALELO

A seção do condutor (Scu) é determinada pela corrente eficaz no indutor e pela densidade máxima de corrente:

Scu =

ILef

Jmax

(41)

Capítulo 11. PROJETO DO INDUTOR | 32

Onde:
- ILef = 3,96A
- Jmax = 600A/cm²

Substituindo os valores na Equação 4:

Scu =

3,96A
600A/cm²

= 0,00660 cm²

Este valor de Scu = 0,00660 cm² está em concordância com o fornecido pela planilha.

Devido à alta frequência de operação (50kHz), o efeito pelicular (skin effect) deve ser considerado. A profundidade pelicular (Δ) é calculada por:

Δ =

7,5
√
fs | (42)

Onde fs = 50kHz.

Δ =

7,5
p
50 × 10³

=

7,5
√
50000

=

7,5
223,607

≈ 0,03354 cm

O diâmetro máximo do fio (Dfio) para mitigar o efeito pelicular é aproximadamente 2Δ:

Dfio = 2 × Δ | (43)

Dfio = 2 × 0,03354 cm = 0,06708 cm

Com o Dfio ≈ 0,06708 cm, a bitola do condutor escolhida foi Equação 22 AWGEquação
(diâmetro de 0,0644 cm e área de 0,003255 cm² | ). Note que o diâmetro do AWG22 é

ligeiramente menor que o Dfio calculado, o que sugere a necessidade de condutores em paralelo. O número de condutores em paralelo (ncond ) é calculado para garantir que a área total de cobre seja suficiente, levando em conta o efeito pelicular. Usando o Scu (Área da bitola do condutor) e Sfio_individual (Área do cobre cujo diâmetro máximo

é limitado por Dfio):

ncondutores =

Scu
Sfio_individual

≈

Área requerida
Área de um fio para skin effect | (44)

Da planilha, Scu (que é a área de um fio 22 AWG) = 0,003255 cm²
. A área de con-
dutor necessária total para ILef = 3,96A e Jmax = 600A/cm² é 0,00660 cm² | . Assim:

ncondutores =

0,00660 cm²
0,003255 cm² ≈ 2,0282 A planilha arredondou para 2 condutores em paralelo.
O comprimento total do fio (lfio) é dado por:
lfio = N × lme | (45)

Onde:
- N = 56 espiras
- lme = 6,7 cm = 0,067 m (comprimento médio de uma espira) lfio = 56 × 0,067 m ≈ 3,752 m

Capítulo 11. PROJETO DO INDUTOR | 33

11.5 CÁLCULO DAS PERDAS

As perdas no indutor são divididas em perdas no cobre (Pcobre) e perdas no núcleo (Pnucleo).

11.6 PERDAS NO COBRE (Pcobre)

As perdas no cobre são devidas ao efeito Joule e são calculadas por:

Pcobre = Rcobre × I

2
Lef | (46)

Onde a resistência do cobre (Rcobre) é:

Rcobre =

ρfio × lfio

ncondutores × Scu_individual

(47)

Considerando os valores da planilha:
- ρfio = 0,00053 ohms/°C (resistividade do fio)
- lfio = 3,75 m
- ncondutores = 2
- Scu_individual = 0,003255 cm² = 0,003255 × 10⁻⁴ m² (Área de um condutor

AWG22)

- ILef = 3,96A

Rcobre =

0,00053 × 3,75 × 10⁻²)
2 × (0,003255
Rcobre ≈ 0,003055Ω

Agora, calculamos Pcobre:

Pcobre = 0,003055Ω × (3,96A)²

Pcobre ≈ 0,05W

11.7 PERDAS NO NÚCLEO (Pnucleo)

As perdas no núcleo são causadas por histerese e correntes parasitas, e são calculadas por:

Pnucleo = ΔB

2,4 × (Kh × fs + Kf × f

2
s
) × Vnucleo | (48)

Onde:
- ΔB

2,4 é um dado de entrada da planilha de 0,00004194.

- Kh = 4,0 × 10⁻⁵ s (coeficiente de perdas por histerese)

Capítulo 11. PROJETO DO INDUTOR | 34
- Kf = 4,0 × 10⁻¹⁰ s

2
(coeficiente de perdas por correntes parasitas)
- fs = 50kHz = 50 × 10³ Hz
- Vnucleo = 8,00 cm³
(volume do núcleo)
Substituindo os valores na Equação 11:

Pnucleo = 0,00004194 × (4,0 × 10⁻⁵ × 50 × 10³ + 4,0 × 10⁻¹⁰ × (50 × 10³ )

2
| ) × 8,00
Pnucleo = 0,00004194 × (4,0 × 50 × 10⁻² + 4,0 × 10⁻¹⁰ × 2500 × 10⁶ ) × 8,00

Pnucleo = 0,00004194 × (2,0 + 1,0) × 8,00

Pnucleo = 0,00004194 × 3,0 × 8,00

Pnucleo ≈ 0,00100656 W

11.8 ELEVAÇÃO DE TEMPERATURA (ΔT)

A elevação de temperatura do núcleo é um indicador da eficiência térmica do projeto e é calculada por:

ΔT = (Pcobre + Pnucleo) × Rth,nucleo | (49)

Onde a resistência térmica do núcleo (Rth,nucleo) é:

Rth,nucleo = 23 × (Ae × Aw )

–0,37 [°C/W] | (50)

Calculando Rth,nucleo:
- Ae = 1,2 cm²
- Aw = 0,85 cm²
- Ae × Aw = 1,2 × 0,85 = 1,02 cm⁴

Rth,nucleo = 23 × (1,02)⁻⁰,37

Rth,nucleo ≈ 23 × 0,9927

Rth,nucleo ≈ 22,83 °C/W

Agora, calculamos ΔT usando os valores de perdas da planilha:
- Pcobre = 0,05W
- Pnucleo = 0,00100656W

ΔT = (0,05W + 0,00100656W) × 22,83 °C/W

ΔT ≈ 1,40 °C

Capítulo 11. PROJETO DO INDUTOR | 35

11.9 POSSIBILIDADE DE EXECUÇÃO

A possibilidade de execução verifica se é possível alocar o enrolamento na janela do núcleo escolhido. A área mínima da janela necessária (Aw,min) é:

Aw,min =

N × ncondutor × Sfio_iso
Kw

(51)

Onde:
- N = 56 espiras
- ncondutor = 2 (número de condutores em paralelo)
- Sfio_iso = 0,004013 cm²
(área de um condutor AWG22 com isolamento, da planilha)
- Kw = 0,8

Aw,min =

56 × 2 × 0,004013
0,8

Aw,min =

0,449456
0,8
Aw,min ≈ 0,5618 cm²

A possibilidade de execução (Exec) é definida por:

Exec =

Aw,min
Aw

(52)

Onde Aw = 0,85 cm²
(da Tabela do Núcleo NEE-30/14).

Exec =

0,5618 cm²
0,85 cm²

≈ 0,6609

Este valor de Exec ≈ 0,6609 (ou 66,09%) indica que a área mínima necessária é menor que a área da janela disponível (Exec < 1), confirmando que é possível construir o enrolamento no núcleo escolhido. A planilha forneceu Exec = 0,6610, o que indica uma excelente concordância.

36

### 12 PROJETO DO TRANSFORMADOR

O projeto de um transformador para conversores Forward envolve o dimensionamento do núcleo magnético e dos enrolamentos primário, secundário e terciário (de desmagnetização), visando garantir a correta relação de tensões, minimizar perdas e evitar a saturação do núcleo. Para este projeto, trata-se especificamente de um transformador monofásico de três enrolamentos. A seguir, detalha-se o passo a passo do cálculo do projeto do transformador.

12.1 ESPECIFICAÇÕES E DADOS INICIAIS

Os dados de entrada para o projeto do transformador são obtidos das especificações do conversor e incluem:

Tabela 7 – Especificações e Dados Iniciais do Projeto do Transformador

Parâmetro | Valor
Tensão de entrada (Vin) | 100 V
Tensão de saída (Vo) | 12,5 V
Potência de saída (Po) | 50 W
Frequência de comutação (fs) | 50 kHz
Relação de espiras (n = NP/NS) | 2
Densidade de fluxo máxima (Bmax ) | 0,3 T
Densidade Máxima de corrente (Jmax ) | 600 A cm²
Fator de ocupação do enrolamento (Kw ) | 0,8
Fator de ocupação do primário (Kp) | 0,6
Resistividade do fio (pfio) | ◦C 0,000668 Ω/
Subida máxima de temperatura permitida (ΔT) | 35◦C
Temperatura ambiente (Ta) | 25◦C
Comprimento médio de uma espira (Lespira) | 6,7 cm
Comprimento do caminho magnético (Lme) | 6,7 cm
Volume do núcleo (Ve) | 8,00 cm³

Capítulo 12. PROJETO DO TRANSFORMADOR | 37

Tabela 8 – Resultados dos Cálculos Principais do Projeto do Transformador

Parâmetro | Valor Calculado/Obtido
AWG (Primário) | 23
NP | 49 voltas
ncond (Primário) | 0,8391
Tamanho do chicote (Primário) | 4,3
AWG (Secundário) | 22
NS | 24,7 voltas
ncond (Secundário) | 0,6661
Tamanho do chicote (Secundário) | 2,7
AWG (Terciário) | 28
NT | 49,5 voltas
ncond (Terciário) | 0,9191
Tamanho do chicote (Terciário) | 4,3
Resultados Gerais
Núcleo Escolhido | NEE-30/14
P | 0,6
Exec total | 0,4
ΔBmax | 0,6 T

12.2 SELEÇÃO DO NÚCLEO MAGNÉTICO

A seleção do núcleo é baseada na capacidade de armazenamento de energia e na área disponível para os enrolamentos.
O produto Ae · Aw é calculado como:

Ae · Aw =

Np · Iprimeficaz
Jmax · Kp · Kw

(53)

Ae · Aw = 0,1157 cm⁴

Com base neste valor e em catálogos de fabricantes, selecionamos um núcleo cujas dimensões estão listadas abaixo, com seus respectivos valores de área de seção transversal (Ae), área da janela (Aw ), volume do núcleo (Ve) e comprimento médio da espira (Lespira):
- Ae = 1,2 cm²
- Aw = 0,85 cm²
- Comprimento médio de uma espira (Lespira): 6,7 cm
- Comprimento do caminho magnético (Lme): 6,7 cm
- Volume do núcleo (Ve): 8,00 cm³

As dimensões físicas do núcleo, como espessura (A, B) e comprimento (C, D) da janela, também são obtidas da tabela para o núcleo escolhido:

Capítulo 12. PROJETO DO TRANSFORMADOR | 38
- Espessura do núcleo (A): 0,72 cm
- Comprimento do núcleo (B): 0,73 cm
- Espessura da janela (C): 0,490 cm
- Comprimento da janela (D): 1,81 cm A espessura do fio (Δ) é calculada com base na frequência de comutação:

Δ = 7,5/p
fs | (54)
Δ = 7,5/√
50.000 ≈ 0,034 cm

O diâmetro do fio (Dfio) é então calculado como:

Dfio = 2 · Δ | (55)

Dfio = 2 · 0,034 cm ≈ 0,067 cm

12.3 DIMENSIONAMENTO DO ENROLAMENTO PRIMÁRIO

- Número de Espiras do Primário (NP):

NP =

Vp · 10⁴ 4 · Bmax · Ae | (56)

NP ≈ 49 voltas

- Área da Bitola do Condutor (SL
): A área da bitola do condutor é determinada pela corrente eficaz que passa pelo primário e pela densidade máxima de corrente permitida no fio.

SL =

ILeficaz

Jmax

(57)

SL =

1,3 A
600 A/cm²

≈ 0,002167 cm²

- Área do Cobre (Scu) e com Isolamento (Scui): Estes valores são escolhidos

com base em tabelas de fios e o diâmetro máximo do fio (Dfio).

– Scu = 0,002582 cm²

– Scui = 0,003221 cm²

- Número de Condutores em Paralelo (ncond ): Se a área necessária (SL
) for
maior que a área de um único fio disponível (Scu), ou para reduzir o efeito pelicular, múltiplos condutores em paralelo são usados.

ncond =

SL

Scu

(58)

Capítulo 12. PROJETO DO TRANSFORMADOR | 39

ncond =

0,002167
0,002582

≈ 0,8391

Como o resultado é menor que 1, indica que um único condutor com área Scu é suficiente, ou que essa é a fração de área de um fio padrão necessária.

- Área Mínima da Janela Requerida (Awmin): A área mínima da janela neces-

sária para acomodar o enrolamento primário é calculada:

Awmin =

NP · ncond · Scui
Kw

(59)

Awmin =

49 · 1 · 0,003221
0,8

≈ 0,1973 cm²

- Possibilidade de Execução (Exec): Este parâmetro avalia se a janela do núcleo escolhido é grande o suficiente para o enrolamento.

Exec = Awmin
Aw

(60)

Exec = 0,1973 cm²
0,85 cm²

≈ 0,2321

Um valor menor que 1 indica que o enrolamento cabe na janela.

12.4 DIMENSIONAMENTO DO ENROLAMENTO SECUNDÁRIO

- Número de Espiras do Secundário (NS): O número de espiras do secundário é derivado da relação de espiras n e do número de espiras do primário (NP).
NS = NP/n | (61)

NS = 49/2 = 24,72 voltas ≈ 25 voltas

- Área da Bitola do Condutor (SL
): Similar ao primário, usando a corrente eficaz do secundário (Iseceficaz = 1,3 A).

SL =

1,3 A
600 A/cm²

≈ 0,002167 cm²

- Área do Cobre (Scu) e com Isolamento (Scui):

– Scu = 0,003255 cm²

– Scui = 0,004013 cm²

- Número de Condutores em Paralelo (ncond ):

ncond =

0,002167
0,003255

≈ 0,6661

Capítulo 12. PROJETO DO TRANSFORMADOR | 40
- Área Mínima da Janela Requerida (Awmin):

Awmin =

25 · 1 · 0,004013
0,8

≈ 0,1254 cm²

- Possibilidade de Execução (Exec):

Exec = 0,1254 cm²
0,85 cm²

≈ 0,1475

Um valor menor que 1 indica que o enrolamento cabe na janela.

12.5 DIMENSIONAMENTO DO ENROLAMENTO TERCIÁRIO (DESMAGNETIZA-ÇÃO)

- Número de Espiras do Terciário (NT ): Para a desmagnetização adequada do núcleo, o número de espiras do enrolamento terciário é tipicamente igual ao número de espiras do primário (NP).
NT = NP | (62)

NT = 49 voltas

- Área da Bitola do Condutor (SL ): Usando a corrente eficaz do terciário (I

tereficaz = 0,4 A).

SL =

0,4
600 A/cm²

≈ 0,00059 cm²

- Área do Cobre (Scu) e com Isolamento (Scui):

– Scu = 0,000642 cm²

– Scui = 0,000872 cm²

- Número de Condutores em Paralelo (ncond ):

ncond =

0,00059
0,000642

≈ 0,9191 ≈ 1

- Área Mínima da Janela Requerida (Awmin):

Awmin =

49 · 1 · 0,000872
0,8

≈ 0,0534 cm²

- Possibilidade de Execução (Exec):

Exec = 0,0534 cm²
0,85 cm²

≈ 0,0628

Um valor menor que 1 indica que o enrolamento cabe na janela.

Capítulo 12. PROJETO DO TRANSFORMADOR | 41

12.6 PERDAS E POSSIBILIDADE DE EXECUÇÃO TOTAL

As perdas no transformador (P) foram calculadas como a ondulação de fluxo máxima (ΔBmax ) é um parâmetro importante na análise do núcleo magnético e é dada por:

ΔBmax = 2 · Bmax | (63)

ΔBmax = 2 · 0,3 ≈ 0,6T

A possibilidade de execução total, que considera o espaço ocupado por todos os enrolamentos na janela do núcleo, é calculada pela soma das áreas mínimas de janela requeridas por cada enrolamento dividida pela área total da janela do núcleo. A equação para a possibilidade de execução total (Exectotal) é:

Exectotal =

Awmin,primário + Awmin,secundário + Awmin,terciário
Aw

(64)

Exectotal =

0,1973 + 0,1254 + 0,0534
0,85

≈ 0,4

Este valor, sendo menor que 1, indica que todos os enrolamentos cabem na janela disponível, validando a escolha do núcleo.

42

### 13 CÁLCULO TÉRMICO

Com os dados de potência dissipada em cada componente, é possível estimar se é ou não necessário o uso de dissipadores de calor para assegurar a confiabilidade do conversor. Esta estimativa pode ser realizada com base no seguinte cálculo:

Tjm

= Rth,ja · Ptotal + Ta | (65)

Onde Ta é a temperatura ambiente, Rth,ja é a resistência térmica da junção do componente para o ambiente, dada em ◦C/W. Ptotal é a potência dissipada e Tjm a tempera-

tura máxima de junção nesta condição de operação. Se a temperatura encontrada for menor que a temperatura de junção máxima fornecida no datasheet do componente, é seguro utilizar este dispositivo sem o uso de um dissipador de calor. Caso isto não aconteça, é necessário dimensionar um dissipador que tenha a capacidade de retirar o calor emitido pela junção do semicondutor.

13.1 DIODOS (MUR840)

Para o cálculo térmico dos diodos MUR840, é necessário considerar as perdas em condução e as perdas em bloqueio. O datasheet do MUR840 fornece os parâmetros necessários.
As perdas em condução (PCD) são calculadas por:

PCD = VT0

- IDmed + Rd
- I

2
Def | (66)

Onde VT0 e Rd são obtidos da linearização da curva característica VF vs IF . Para o MUR840, a VF é de 1 V para IF = 8,0 A a 150◦C.

As perdas em bloqueio (PBD) são calculadas por:

PBD = VD · QRR · fs | (67)

Onde VD é o valor máximo da tensão no diodo, QRR é a carga armazenada durante a recuperação reversa e fs é a frequência de operação. Para o MUR840, o QRR é de 60 nC a di/dt = 50 A/μs e TJ = 25◦C, ou 50 nC para IF = 0.5 A, IR = 1.0 A, IREC = 0.25 A a TJ = 25◦C. Usaremos 60 nC como valor típico.

Para este projeto, os valores de tensão máxima (VD) e frequência (fs) são:
- VD para D1 e D2: 50 V
- VD para D3: 200 V
- fs: 50.000 Hz
Consideremos as perdas para cada diodo. Para simplificar, assumimos um VT0 ≈ 1.0 V e Rd ≈ 0 Ω (considerando o ponto de operação típico do diodo).

Capítulo 13. CÁLCULO TÉRMICO | 43

### 13.1.1 Para Diodo D1:

As correntes média e eficaz são ID1med = 0,9875 A e ID1rms = 1,975 A. As perdas em condução PCD1
são:

PCD1 = 1,0 V · 0,9875 A = 0,9875 W

As perdas em bloqueio PBD1 são:

PBD1 = 50 V · (60 · 10⁻⁹ C) · 50.000 Hz = 0,00015 W

As perdas totais para D1 são:

Ptotal, D1 ≈ 0,9875 W + 0,00015 W = 0,98765 W

### 13.1.2 Para Diodo D2:

As correntes média e eficaz são ID2med = 2,9625 A e ID2rms = 3,4237 A. As perdas em condução PCD2
são:

PCD2 = 1,0 V · 2,9625 A = 2,9625 W

As perdas em bloqueio PBD2 são:

PBD2 = 50 V · (60 · 10⁻⁹ C) · 50.000 Hz = 0,00015 W

As perdas totais para D2 são:

Ptotal, D2 ≈ 2,9625 W + 0,00015 W = 2,96265 W

### 13.1.3 Para Diodo D3:

As correntes média e eficaz são ID3med = 0,121 A e ID3rms ≈ 1,25 A (usando ID3max ). As perdas em condução PCD3
são:

PCD3 = 1,0 V · 0,121 A = 0,121 W

As perdas em bloqueio PBD3 são:

PBD3 = 200 V · (60 · 10⁻⁹ C) · 50.000 Hz = 0,0006 W

As perdas totais para D3 são:

Ptotal, D3 ≈ 0,121 W + 0,0006 W = 0,1216 W

As características térmicas do MUR840 são:
- Máxima resistência térmica junção-case (RthJC): 2,0 ◦C/W

Capítulo 13. CÁLCULO TÉRMICO | 44
- Faixa de temperatura de junção e armazenamento (TJ

, Tstg): –65 to +175 ◦C

Para o diodo D2, que apresenta as maiores perdas (aproximadamente 2,96 W), a temperatura de junção (Tj

) sem dissipador é calculada usando a resistência térmica junção-ambiente (RthJA). Embora o datasheet do MUR840 não especifique diretamente o RthJA para o encapsulamento TO-220 sem dissipador no modelo MUR840, a Figura 4 do datasheet para TA = 25◦C indica que o MUR840 pode operar com cerca de 8A em onda quadrada com RthJA = 16◦C/W ou RthJA = 60◦C/W (sem dissipador). Utilizaremos RthJA = 60◦C/W (sem dissipador) para o pior caso.

A temperatura de junção Tj é dada por:

Tj = Ta + Ptotal · RthJA

Tj = 25◦C + 2,96 W · 60 ◦C/W = 25◦C + 177,6◦C = 202,6◦C

Esta temperatura de junção (202,6◦C) excede a temperatura máxima de junção permitida de 175◦C para o MUR840. Portanto, é necessário o uso de dissipador para os

diodos, especialmente para D2.

13.2 MOSFET (IRF740)

Para o cálculo térmico do MOSFET IRF740, consideramos as perdas em condução e as perdas em comutação.
As perdas em condução (Pcon) são calculadas por:

Pcon = RDS(on)

- I

2
Srms | (68)

A resistência RDS(on)

varia com a temperatura. A RDS(on) a 25◦C é de 0,55 Ω. O fator de correção para 120◦C é de aproximadamente 1,8. Portanto, a RDS(on) a 120◦C é:

RDS(on),120◦C = 0,55 Ω · 1,8 = 0,99 Ω

Utilizando ISrms = 0,9875 A (calculado anteriormente), as perdas em condução são:

Pcon = 0,99 Ω · (0,9875 A)² ≈ 0,99 Ω · 0,975 A² ≈ 0,965 W

As perdas em comutação (Pcom) são dadas por:

Pcom =

fs
2
- (tcon + tcoff) · ISmix · VSmix | (69)

Para o IRF740, os tempos de comutação são:
- td(on) = 14 ns (atraso de ligamento)
- tr = 27 ns (tempo de subida)
- td(off) = 50 ns (atraso de desligamento)

Capítulo 13. CÁLCULO TÉRMICO | 45
- t

f = 24 ns (tempo de queda) Para uma estimativa simplificada das perdas de comutação:
- Tempo de condução (tcon):

tcon ≈ td(on) + tr = 14 ns + 27 ns = 41 ns

- Tempo de corte (tcoff):

tcoff ≈ td(off) + t
f = 50 ns + 24 ns = 74 ns
- Corrente de pico na comutação (ISmix ): ≈ ISwmax = 3,25 A
- Tensão de pico na comutação (VSmix ): ≈ VSwmax = 200 V Calculando as perdas em comutação:

Pcom =

50.000 Hz
2
- (41 · 10⁻⁹ s + 74 · 10⁻⁹ s) · 3,25 A · 200 V

Pcom = 25.000 Hz · (115 · 10⁻⁹ s) · 650 W

Pcom ≈ 1,868 W

As perdas totais no interruptor (PS) são a soma das perdas em condução e comutação:

PS = Pcon + Pcom | (70)

PS = 0,965 W + 1,868 W = 2,833 W

As características térmicas do IRF740 são:
- Máxima resistência térmica junção-case (RthJC): 1,0 ◦C/W
- Máxima resistência térmica junção-ambiente (RthJA): 62 ◦C/W (sem dissipa-

dor)

- Faixa de temperatura de junção e armazenamento (TJ

, Tstg): –55 to +150 ◦C

A temperatura de junção (Tj

) sem dissipador é calculada por:

Tj = Ta + PS · RthJA

Tj = 25◦C + 2,833 W · 62 ◦C/W = 25◦C + 175,6 ◦C = 200,6 ◦C

Esta temperatura de junção (200,6◦C) excede a temperatura máxima de junção permitida de 150◦C para o IRF740. Portanto, é necessário o uso de um dissipador para o

MOSFET.

Capítulo 13. CÁLCULO TÉRMICO | 46

13.3 DIMENSIONAMENTO DO DISSIPADOR

Como tanto o diodo (D2 com as maiores perdas) quanto o MOSFET (S) excedem suas temperaturas de junção máximas sem dissipador, é necessário dimensionar dissipadores para garantir a operação confiável dos componentes. O dimensionamento do dissipador consiste em determinar a resistência térmica dissipador-ambiente (Rda) que consiga conduzir o calor para fora do dispositivo, mantendo a temperatura de junção abaixo do limite estabelecido.
A resistência térmica total junção-ambiente (RthJA) com dissipador é expressa por:
RthJA = RthJC + RthCS + Rda | (71)

Para que a temperatura de junção (Tj

) permaneça dentro do limite especificado, o requisito para a resistência térmica junção-ambiente total é:

RthJA ≤

Tj,max – Ta

Ptotal

(72)

Para os cálculos a seguir, utilizaremos uma temperatura máxima de junção desejada (Tj,max ) de 125◦C para um projeto conservador e a temperatura ambiente (Ta) de 25◦C.

### 13.3.1 Para o Diodo (MUR840)

Para o diodo D2, que apresentou as maiores perdas:
- Potência total dissipada (Ptotal): 2,96 W
- Resistência térmica junção-caixa (RthJC): 2,0 ◦C/W

O requisito para a resistência térmica junção-ambiente (RthJA) é:

RthJA ≤

125◦C – 25◦C
2,96 W =

100◦C

2,96 W

≈ 33,78 ◦C/W

Considerando uma resistência térmica da interface caixa-dissipador (RthCS) de 0,5 ◦C/W

(valor típico para pasta térmica sem isolador), a resistência térmica do dissipador para o ambiente (Rda) requerida é:

Rda ≤ RthJA – RthJC – RthCS

Rda ≤ 33,78 ◦C/W – 2,0 ◦C/W – 0,5 ◦C/W = 31,28 ◦C/W

Portanto, um dissipador com resistência térmica menor ou igual a 31,28 ◦C/W é neces-

sário para o diodo.

Capítulo 13. CÁLCULO TÉRMICO | 47

### 13.3.2 Para o MOSFET (IRF740)

Para o MOSFET:
- Potência total dissipada (Ptotal): 2,833 W
- Resistência térmica junção-caixa (RthJC): 1,0 ◦C/W

O requisito para a resistência térmica junção-ambiente (RthJA) é:

RthJA ≤

125◦C – 25◦C
2,833 W | = 100◦C
| 2,833 W ≈ 35,30 ◦C/W

Considerando uma resistência térmica da interface caixa-dissipador (RthCS) de 0,5 ◦C/W

(valor típico para pasta térmica), a resistência térmica do dissipador para o ambiente (Rda) requerida é:

Rda ≤ RthJA – RthJC – RthCS

Rda ≤ 35,30 ◦C/W – 1,0 ◦C/W – 0,5 ◦C/W = 33,80 ◦C/W

Conclui-se que um dissipador com resistência térmica menor ou igual a 33,80 ◦C/W é

necessário para o MOSFET.

48

### 14 PCB DO CONVERSOR FORWARD

A placa de circuito impresso de potência foi projetada com o programa Altium Designer. Abaixo pode ser visto o esquemático do projeto. No esquemático estão representados tanto o circuito do conversor, quanto a entrada para o circuito de comando.

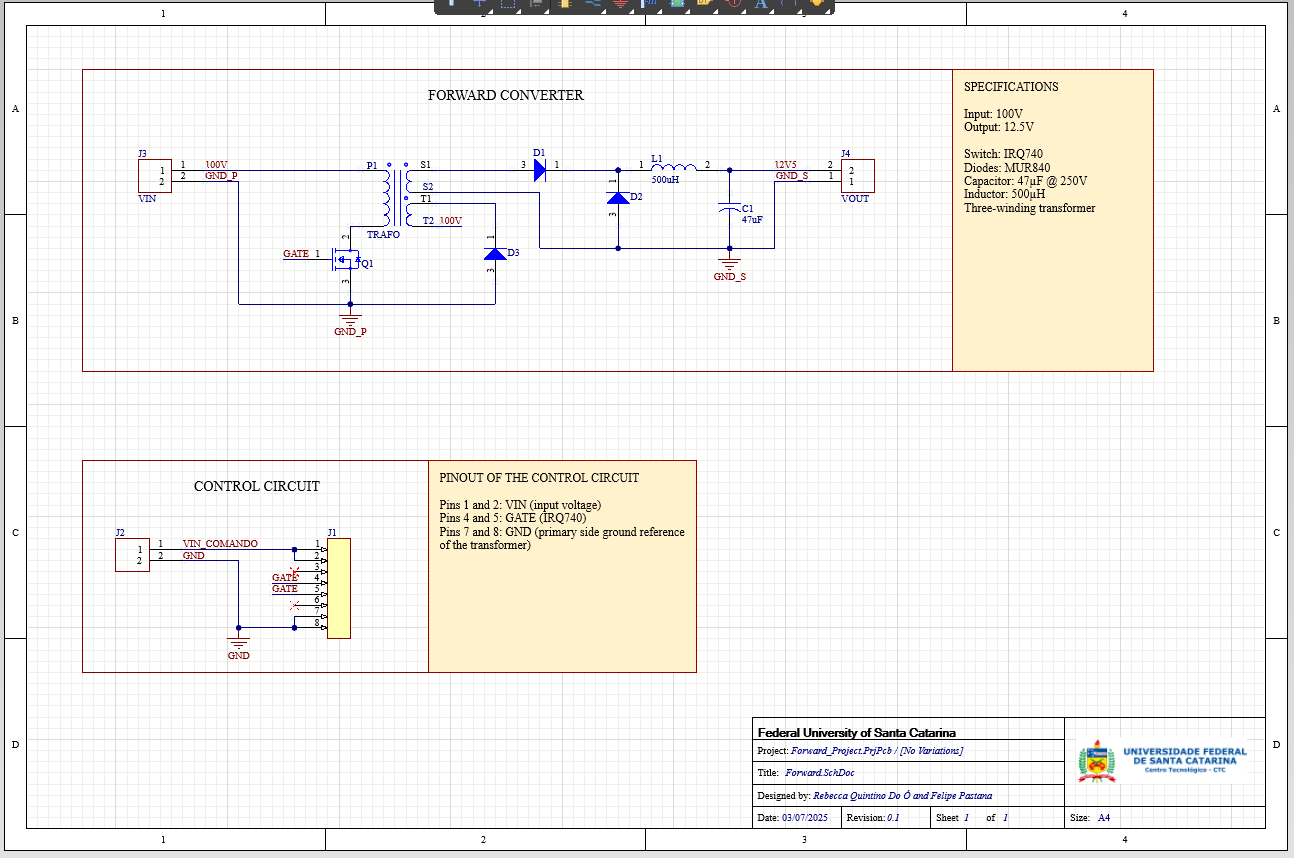
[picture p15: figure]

Figura 20 – Esquemático Altium.

Os modelos 3D estão disponíveis para uma visualização mais precisa das dimensões e do posicionamento dos componentes, ajudando a prevenir interferências ou problemas durante a soldagem. O layout da placa de potência e sua representação em 3D podem ser conferidos nas figuras a seguir.

Capítulo 14. PCB DO CONVERSOR FORWARD | 49

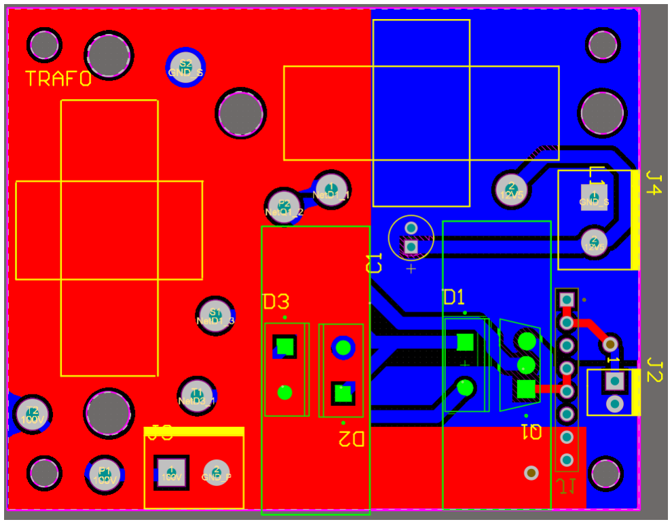
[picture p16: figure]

Figura 21 – PCB top layer.

Capítulo 14. PCB DO CONVERSOR FORWARD | 50

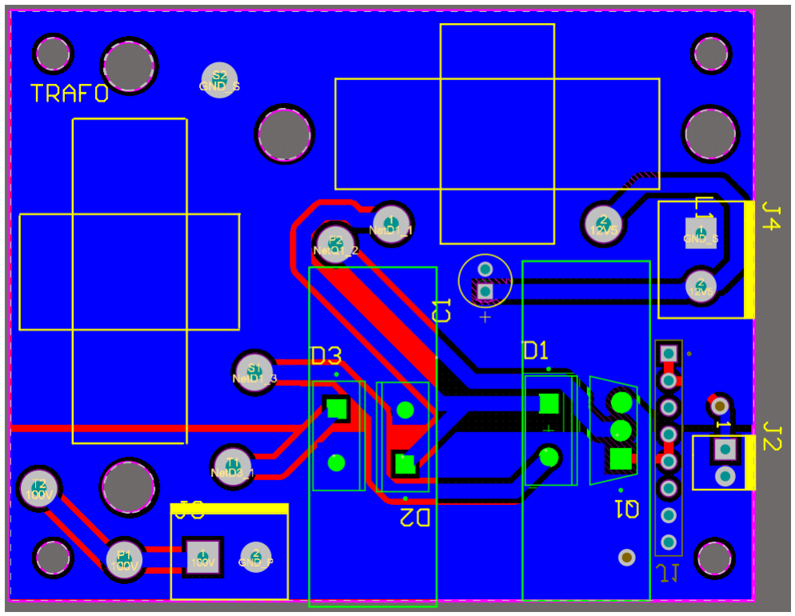
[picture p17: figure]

Figura 22 – PCB bottom layer.

Capítulo 14. PCB DO CONVERSOR FORWARD | 51

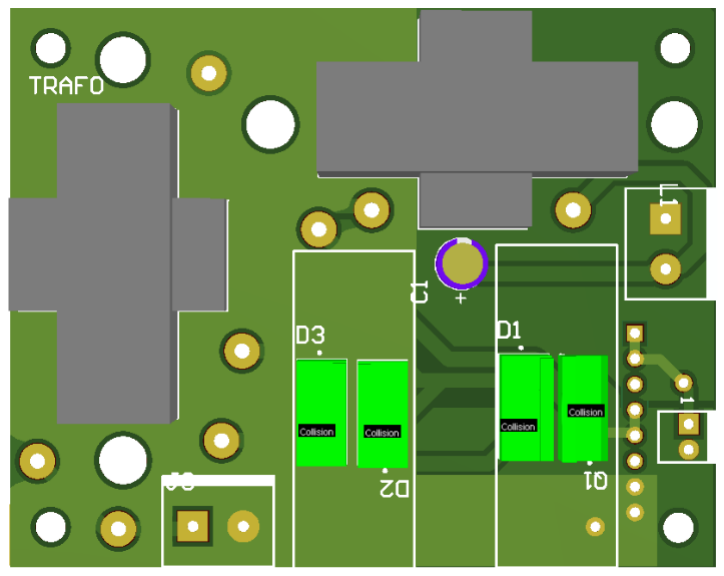
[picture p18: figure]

Figura 23 – Modelo 3D visto de cima.

O design final da placa resultou em uma PCB com 69,98 X 55,50 mm, como mostra a figura abaixo, indicando um bom aproveitamento do espaço por conta da dimensão reduzida que foi possível obter.

Capítulo 14. PCB DO CONVERSOR FORWARD | 52

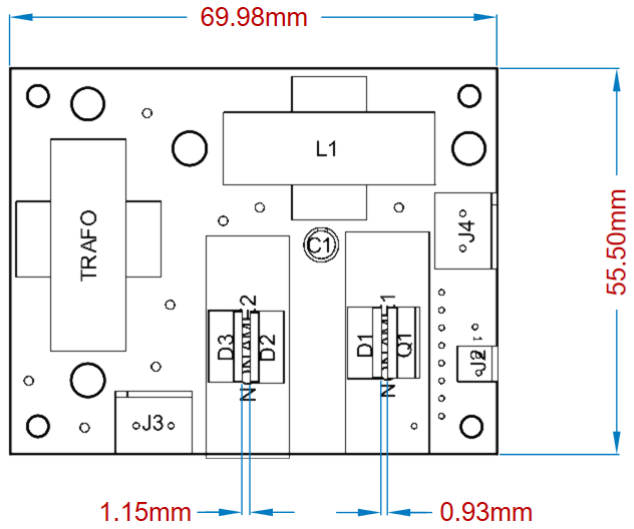
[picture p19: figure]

Figura 24 – Dimensões PCB

Uma imagem da placa finalizada com os componentes já soldados e com o circuito de comando já conectado pode ser vista a seguir.

Capítulo 14. PCB DO CONVERSOR FORWARD | 53

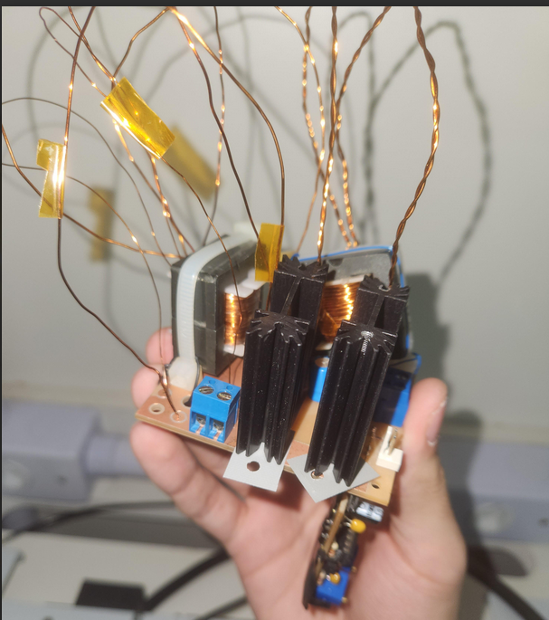
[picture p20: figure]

Figura 25 – PCB montada.

14.1 LISTA DE COMPONENTES

A lista de componentes utilizados para a confecção da PCB do transformador forward é mostrada na abaixo.

Capítulo 14. PCB DO CONVERSOR FORWARD | 54

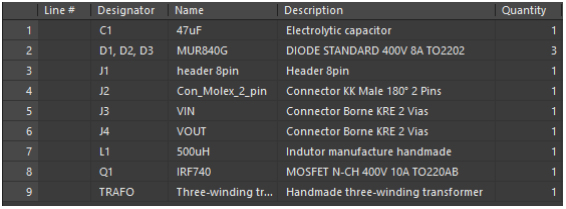
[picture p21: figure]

Figura 26 – Tabela de componentes.

55

### 15 RESULTADOS OBTIDOS

Para os testes do desempenho do conversor foi realizado o experimento em bancada com a utilização do osciloscópio para a verificação do sinal de saída e também as correntes nos enrolamentos do transformador e do indutor.
No teste foi utilizada uma carga de 17,6 Ω, um pouco maior do que a carga projetada. Inicialmente mediu-se com o osciloscópio a corrente no enrolamento do indutor e a tensão de saída.

Capítulo 15. RESULTADOS OBTIDOS | 56

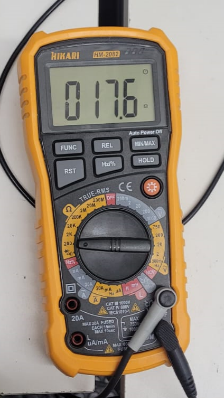
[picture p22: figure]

Figura 27 – Medição da carga.

Capítulo 15. RESULTADOS OBTIDOS | 57

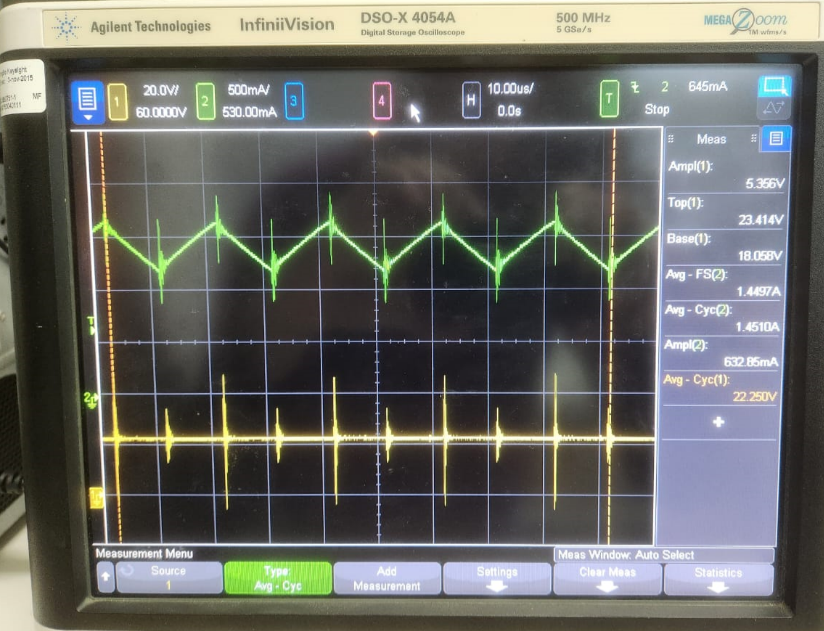
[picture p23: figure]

Figura 28 – Tensão de saída e corrente no indutor.

Através da figura obteve-se que a corrente média no indutor é de 1,45 A com amplitude de 632,85 mA, enquanto a tensão média na carga foi de 22,50 V. Na imagem também é possível perceber os picos de variação na corrente e na tensão devido à comutação da chave de comando.
Em seguida ia ser feita a medição da corrente na entrada do conversor para verificar se havia saturação no transformador, porem, ao ir aumentando gradualmente a tensão da fonte de bancada até 100 V ocorreu que, por volta dos 80 V, a fonte de alcançou o limite máximo de corrente programado, zerando a tensão para evitar problemas, entretanto, a fazer isso gerou um transitório que queimou os transistores da placa de comando e não foi possível realizar mais testes.

58

### 16 DISCUSSÕES

Durante o teste houve alguns problemas. O primeiro problema foi a placa do circuito de comando não funcionar como o esperado, e, portanto, foi necessário utilizar uma previamente pronta. O segundo problema foi a fonte de bancada desligar e queimar a placa do circuito de comando e por conta disso não foi possível realizar mais medições para verificar o funcionamento e a eficiência do transformador forward projetado. Embora não tenha sido realizar mais medições, as medidas no osciloscópio momentos antes de queimar o comando indicavam que havia uma baixa saturação no transformador.

59

### 17 CONCLUSÃO

O desenvolvimento deste projeto de conversor Forward abrangeu tanto a fundamentação teórica quanto a implementação prática, com a simulação e montagem do circuito. A etapa teórica foi concluída com sucesso, validando o dimensionamento dos componentes, a seleção do núcleo magnético e o comportamento esperado do conversor por meio de análises e simulações.
No entanto, devido a problemas técnicos durante a fase de testes não foi possível validar plenamente o funcionamento prático do protótipo.
Apesar disso, o trabalho proporcionou um aprendizado valioso sobre o projeto de conversores chaveados, reforçando a necessidade de planejamento detalhado e testes incrementais. Em síntese, o projeto atingiu seus objetivos teóricos e identificou pontos críticos para aprimoramento prático, servindo como base para desenvolvimentos futuros na área de conversores de potência.

60

### 18 REFERÊNCIAS BIBLIOGRÁFICAS

1. Martins C. D., Conversores CC-CC Básicos Isolados. Edição do Autor., Florianópolis

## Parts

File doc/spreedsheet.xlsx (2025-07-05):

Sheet: Entrada de dados
Dado | Descrição | Valor | Unidade | Equação | Tipo
Vin | Tensão de alimentação da fonte antes do conversor. | 100 | V |  | Dado
Vo | Tensão desejada na saída do conversor. | 12.5 | V |  | Dado
Po | Potência desejada na saída do conversor. | 50 | W |  | Dado
fs | Frequência de comutação do conversor (Hz). | 50000 | Hz |  | Dado
ΔIL | Ondulação da corrente nos indutores | 0.2 | % |  | Dado
ΔVo | Ondulação da tensão em Vo | 0.02 | % |  | Dado
D | Razão cíclica | 0.25 | __ |  | Dado
Ro | Resistência de carga | 3.12 | ohm | Vo²/Po | Calculado
Io | Corrente média de saída | 3.96 | A |  | Medido
Iin | Corrente de entrada | 0.50 | A | Po/Vin | Calculado
L | Valor do indutor de saída que suaviza a corrente. | 0.0005 | H |  | Dado
C | Valor do capacitor de saída que suaviza a tensão. | 4.7e-05 | F |  | Dado
ΔIL | Ondulação de corrente no indutor L | 0.10 | A | ΔIL * Iin | Calculado
ΔVo | Ondulação da tensão na tensão de saída | 0.25 | V | ΔVo*Vo | Calculado
ΔT | Subida máxima de temperatura permitida no indutor | 35 | °C |  | Dado
Ta | Temperatura ambiente | 25 | °C |  | Dado
Np |  | 2 |  |  | Dado
Ns |  | 1 |  |  | Dado
Nt |  | 2 |  |  | Dado

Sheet: Dados da Simulação
 |  | Simulação
Parâmetro | Descrição | Máx | Médio | Eficaz | Variação | Unidade
Vin | Tensão de entrada | 100 | 100 | 100 |  | V
Vo | Tensão de saída | 12.38 | 12.37 | 12.37 |  | V
IL | Corrente no Indutor Li | 4 | 3.96 | 3.96 |  | A
IC | Corrente no capacitor Ci | 0.16 | -0.0014 | 3.96 |  | A
Vs | Tensão no interruptor S | 200 | 9974 | 12.21 |  | V
Is | Corrente no interruptor S | 3.34 | 0.649 | 1.31 |  | A
ID1 | Corrente do diodo 1 | 4.12 | 0.979 | 1.98 |  | A
ID2 | Corrente do diodo 2 | 4.14 | 2.97 | 3.43 |  | A
ID3 | Corrente do diodo 3 | 1.1 | 0.154 | 0.355 |  | A
VD1 | Tensão no diodo 1 | 2.47e-06 | -12.4 | 24.54 |  | V
VD2 | Tensão no diodo 2 | 7.4e-06 | -123.78 | 24.44 |  | V
VD3 | Tensão no diodo 3 | 5.37e-06 | -100.13 | 122.02 |  | V
Vpri | Tensão do primário | 99.99 | 0.0188 | 71.25 |  | V
Vsec | Tensão do secundário | 49.82 | 0.038 | 34.96 |  | V
Vter | Tensão do terciário | 99.69 | 0.138 | 70.35 |  | V
Ipri | Corrente no primário | 3.06 | 0.642 | 1.3 |  | A
Isec | Corrente no secundário | 4.02 | 0.977 | 1.3 |  | A
Iter | Corrente no terciário | 9.97e-06 | -0.153 | 0.354 |  | A
ΔIL0 | Variação da corrente do indutor |  |  |  | 0.346 | A
ΔV0 | Variação da tensão do capacitor |  |  |  | 0.0193 | V

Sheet: Núcleo (indutor)
Parâmetro | Símbolo | Descrição | Valor [m] | Unidade
 | Ac (Ae) | Área da seção transversal do núcleo por onde passa o fluxo magnético (m²). | 0.00012 | m²
 | Wa (Aw) | Área da janela onde os enrolamentos de fio são posicionados (m²). | 8.5e-05 | m²
 | Ap (Ae.Aw) | Produto de Ac × Wa. Define a capacidade do núcleo de armazenar energia e acomodar enrolamentos (m⁴). | 1.02e-08 | m⁴
 | lc (Ie) | Comprimento médio do caminho magnético do núcleo (m). | 0.0670 | m
 | Vc (Ve) | Volume total do núcleo (m³). | 8e-06 | m³
 | MLT (lt) | Comprimento médio de uma espira (m). Utilizado no cálculo da resistência dos enrolamentos. | 0.0670 | m
 | A | Espessura do núcleo | 0.72 | cm
 | B | Comprimento do núcleo | 1.46 | cm
 | C | Espessura da janela | 0.455 | cm
 | D | Comprimento da janela | 1.80 | cm
Parâmetro calculado
Ae.Aw | 0.5500 | m⁴
 |  |  |  |  | https://www.thornton.com.br/produtos/nee.htm
Escolhido E-30/14 |  |  |  | Núcleo | Ae [cm²] | Aw [cm²] | Ie [cm] | It [cm] | Ve [cm³] | AeAw [cm⁴]
Ae | 1.2 | cm² |  | E-20 | 0.312 | 0.26 | 4.28 | 3.8 | 1.34 | 0.08
Aw | 0.85 | cm² |  | E-30/7 | 0.6 | 0.8 | 6.7 | 5.6 | 4 | 0.48
le | 6.7 | cm² |  | E-30/14 | 1.2 | 0.85 | 6.7 | 6.7 | 8 | 1.02
lt | 6.7 | cm |  | E-42/15 | 1.81 | 1.57 | 9.7 | 8.7 | 17.1 | 2.84
Ve | 8 | cm³ |  | E-42/20 | 2.4 | 1.57 | 9.7 | 10.5 | 23.3 | 3.77
Ae.Aw | 1.02 | cm⁴ |  | E-55 | 3.54 | 2.5 | 11.2 | 11.6 | 42.5 | 8.85

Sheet: Fio (indutor)
Parâmetro | Símbolo | Descrição | Valor | Unidade
Resistividade do cobre a 20°C | rw_20 | Resistência do cobre por metro a 20 °C. | 8.3e-05 | Ω·m
Coef. temp. da resistividade | a20 | Variação da resistividade do cobre com a temperatura. | 0.00422 | 1/°C
Resistividade do cobre a 100°C | rw_100 | Resistência do cobre por metro a 100 °C. | 0.000111
Fator de perda no núcleo | g | Relação entre perda no núcleo e perda no cobre (assumido zero neste exemplo). | 0 | —
Parâmetro calculado
Diâmetro do cobre calculado | 0.06708 | cm
Área do cobre calculado | 0.006600 | cm
Corrente consumida | 3.96 | A
AWG22 escolhido
Diâmetro do cobre | 0.064 | cm |  |  | AWG | Diâmetro Cobre [cm] | Área Cobre [cm²] | Diâmetro Isolamento [cm] | Área Isolamento [cm²] | Resistividade 20°C [Ω/°C] | Resistividade 100°C [Ω/°C] | Corrente [A] (450A/cm²)
Área do cobre | 0.003255 | cm² |  |  | 10 | 0.259 | 0.05262 | 0.273 | 0.058572 | 3.3e-05 | 4.4e-05 | 23.679
Corrente 450A/cm² | 1.465 | A |  |  | 11 | 0.231 | 0.041729 | 0.244 | 0.046738 | 4.1e-05 | 5.5e-05 | 18.778
Resistividade do cobre a 20°C | 0.00053 |  |  |  | 12 | 0.205 | 0.033092 | 0.218 | 0.037309 | 5.2e-05 | 7e-05 | 14.892
Resistividade do cobre a 100°C | 0.000708 |  |  |  | 13 | 0.183 | 0.026243 | 0.195 | 0.029793 | 6.6e-05 | 8e-05 | 11.809
 | 0.004013 |  |  |  | 14 | 0.163 | 0.020811 | 0.174 | 0.0238 | 8.3e-05 | 0.000111 | 9.365
 |  |  |  |  | 15 | 0.145 | 0.016504 | 0.156 | 0.019021 | 0.000104 | 0.00014 | 7.427
 |  |  |  |  | 16 | 0.129 | 0.013088 | 0.139 | 0.015207 | 0.000132 | 0.000176 | 5.890
 |  |  |  |  | 17 | 0.115 | 0.010379 | 0.124 | 0.012164 | 0.000166 | 0.000222 | 4.671
 |  |  |  |  | 18 | 0.102 | 0.008231 | 0.111 | 0.009735 | 0.000209 | 0.00028 | 3.704
 |  |  |  |  | 19 | 0.091 | 0.006527 | 0.1 | 0.007794 | 0.000264 | 0.000353 | 2.937
 |  |  |  |  | 20 | 0.081 | 0.005176 | 0.089 | 0.006244 | 0.000333 | 0.000445 | 2.329
 |  |  |  |  | 21 | 0.072 | 0.004105 | 0.08 | 0.005004 | 0.00042 | 0.000561 | 1.847
 |  |  |  |  | 22 | 0.064 | 0.003255 | 0.071 | 0.004013 | 0.00053 | 0.000708 | 1.465
 |  |  |  |  | 23 | 0.057 | 0.002582 | 0.064 | 0.003221 | 0.000668 | 0.000892 | 1.162
 |  |  |  |  | 24 | 0.051 | 0.002047 | 0.057 | 0.002586 | 0.000842 | 0.001125 | 0.921
 |  |  |  |  | 25 | 0.045 | 0.001624 | 0.051 | 0.002078 | 0.001062 | 0.001419 | 0.731
 |  |  |  |  | 26 | 0.04 | 0.001287 | 0.046 | 0.001671 | 0.001339 | 0.001789 | 0.579
 |  |  |  |  | 27 | 0.036 | 0.001021 | 0.041 | 0.001344 | 0.001689 | 0.002256 | 0.459
 |  |  |  |  | 28 | 0.032 | 0.00081 | 0.037 | 0.001083 | 0.002129 | 0.002845 | 0.364
 |  |  |  |  | 29 | 0.029 | 0.000642 | 0.033 | 0.000872 | 0.002685 | 0.003587 | 0.289
 |  |  |  |  | 30 | 0.025 | 0.000509 | 0.03 | 0.000704 | 0.003386 | 0.004523 | 0.229
 |  |  |  |  | 31 | 0.023 | 0.000404 | 0.027 | 0.000568 | 0.004269 | 0.005704 | 0.182
 |  |  |  |  | 32 | 0.02 | 0.00032 | 0.024 | 0.000459 | 0.005384 | 0.007192 | 0.144
 |  |  |  |  | 33 | 0.018 | 0.000254 | 0.022 | 0.000371 | 0.006789 | 0.00907 | 0.114
 |  |  |  |  | 34 | 0.016 | 0.000201 | 0.02 | 0.0003 | 0.00856 | 0.011437 | 0.091
 |  |  |  |  | 35 | 0.014 | 0.0016 | 0.018 | 0.000243 | 0.010795 | 0.014422 | 0.072
 |  |  |  |  | 36 | 0.013 | 0.000127 | 0.016 | 0.000197 | 0.013612 | 0.018186 | 0.057
 |  |  |  |  | 37 | 0.011 | 0.0001 | 0.014 | 0.00016 | 0.017165 | 0.022932 | 0.045
 |  |  |  |  | 38 | 0.01 | 8e-05 | 0.013 | 0.00013 | 0.021644 | 0.028917 | 0.036
 |  |  |  |  | 39 | 0.009 | 6.3e-05 | 0.012 | 0.000106 | 0.027293 | 0.036464 | 0.028
 |  |  |  |  | 40 | 0.008 | 5e-05 | 0.01 | 8.6e-05 | 0.034417 | 0.045981 | 0.023
 |  |  |  |  | 41 | 0.007 | 4e-05 | 0.009 | 7e-05 | 0.043399 | 0.057982 | 0.018

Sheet: Projeto indutor
 | Dado | Descrição | Valor | Arredondamento | Unidade | Equação | Tipo | Anotações
 | Δ |  | 0.034 |  | cm | 7,5/sqrt(fs) | Calculado
 | Dfio | Calculo da seção do fio e do número de fios em paralelo | 0.067 |  | cm | 2*Δ | Calculado | Utilizar condutores abaixo do AWG21
 | Bmax | Máxima densidade de campo magnético | 0.3 |  | T | 0,7kW | Típico
 | ΔB^2,4 |  | 0.00004194 |  |  | (B*(ΔIL/ILpico))^2,4 | Calculado
 | Jmax | Densidade de corrente | 600 |  | A/cm² |  | Típico
 | Kw | Fator de utilização | 0.8 |  |  |  | Típico
 | Kh | Coeficiente de perdas por histerese | 4e-05 |  |  |  | Típico
 | Kf | Coeficiente de perdas por correntes parasistas | 4e-10 |  |  |  | Típico
 | Ae.Aw | Produto de AeAw | 0.5500 |  | cm⁴ | (L*ILpico*ILrms*10^4)/(Bmax*Jmax*Kw) | Calculado | Núcleo escolhido E-30/14
1.0512 | Ae | Área da seção transversal do núcleo | 1.2 |  | cm² | Ae | Escolhido
0.819 | Aw | Área da seção transversal da janela | 0.85 |  | cm² | Aw | Escolhido
 | Lme |  | 6.7 |  | cm | lt | Escolhido
 | A | Espessura do núcleo | 0.72 |  | cm |  | Escolhido
 | B | Comprimento do núcleo | 1.46 |  | cm |  | Escolhido
 | C | Espessura da janela | 0.455 |  | cm | ((25-15,9)/2)*10^-1 | Escolhido
 | D | Comprimento da janela | 1.80 |  | cm |  | Escolhido
 | Ve | Volume do núcleo | 8.00 |  | cm³ |  | Escolhido
 | lespira | Comprimento médio de uma espira | 6.7 |  | cm |  | Escolhido
 | N | Número de espiras | 55.56 | 56 | voltas | (Jmax*Aw*Kw)/(ILeficaz) | Calculado
 | Entreferro | Entreferro do indutor | 0.0946 |  | cm | (N^2*uo*Ae*10^-2)/(L) | Calculado
 | SL | Área da bitola do condutor | 0.00660 |  | cm² | ILeficaz/Jmax | Calculado | AWG escolhido AWG22
 | Scu | Área do cobre cujo o diâmetro máximo é limitado por Dfio | 0.003255 |  | cm² |  | Escolhido
 | Scui | Área do cobre com isolamento | 0.004013 |  | cm² |  | Escolhido
 | pfio | Resistividade do fio | 0.00053 |  | ohms/°C |  | Escolhido
 | ncond | Número de condutores em paralelo | 2.028 | 2 |  | SL/Scu | Calculado
 | Awmin |  | 0.5618 |  |  | (N*ncond*ScuI)/(Kw) | Calculado
 | Exec | Possibilidade de execução | 0.6610 |  |  | Awmin/Aw | Calculado
 | lfio | Tamanho do fio | 3.75 |  | m | N*Lme | Calculado
 | Rcobre |  | 0.003055
 | Pcobre | Perdas no cobre | 0.05 |  |  | (pfo*lespira*N*ILeficaz^2)/ncondutores | Calculado
 | Pnucleo | Perdas magnéticas | 0.0010065 |  |  | ΔB2,4*(Kh*f+Kf*f^2)*Ve | Calculado
 | ΔT | Elevação de temperatura | 1.40 |  | °C | (Pcobre+Pnucleo)*23*(Ae*Aw)^-0,37 | Calculado
 |  | Tamanho do chicote | 4.752 | m |  |  | Calculado
 |  |  | 2.309401077
 |  | Am: seção transversal

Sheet: Fio (trafo)
Parâmetro | Símbolo | Descrição | Valor | Unidade
Resistividade do cobre a 20°C | rw_20 | Resistência do cobre por metro a 20 °C. | 8.3e-05 | Ω·m
Coef. temp. da resistividade | a20 | Variação da resistividade do cobre com a temperatura. | 0.00422 | 1/°C
Resistividade do cobre a 100°C | rw_100 | Resistência do cobre por metro a 100 °C. | 0.000111
Fator de perda no núcleo | g | Relação entre perda no núcleo e perda no cobre (assumido zero neste exemplo). | 0 | —
Parâmetro calculado
Diâmetro do cobre calculado | 0.06708 | cm
Área do cobre calculado | 0.002167 | cm
Corrente consumida | 3.96 | A
AWG23 escolhido (Primario)
Diâmetro do cobre | 0.057 | cm |  |  | AWG | Diâmetro Cobre [cm] | Área Cobre [cm²] | Diâmetro Isolamento [cm] | Área Isolamento [cm²] | Resistividade 20°C [Ω/°C] | Resistividade 100°C [Ω/°C] | Corrente [A] (450A/cm²)
Área do cobre | 0.002582 | cm² |  |  | 10 | 0.259 | 0.05262 | 0.273 | 0.058572 | 3.3e-05 | 4.4e-05 | 23.679
Corrente 450A/cm² | 1.162 | A |  |  | 11 | 0.231 | 0.041729 | 0.244 | 0.046738 | 4.1e-05 | 5.5e-05 | 18.778
Resistividade do cobre a 20°C | 0.000668 | ohm/°C |  |  | 12 | 0.205 | 0.033092 | 0.218 | 0.037309 | 5.2e-05 | 7e-05 | 14.892
Resistividade do cobre a 100°C | 0.000892 | ohm/°C |  |  | 13 | 0.183 | 0.026243 | 0.195 | 0.029793 | 6.6e-05 | 8e-05 | 11.809
Areá do cobre com isolamento | 0.003221 | cm² |  |  | 14 | 0.163 | 0.020811 | 0.174 | 0.0238 | 8.3e-05 | 0.000111 | 9.365
 |  |  |  |  | 15 | 0.145 | 0.016504 | 0.156 | 0.019021 | 0.000104 | 0.00014 | 7.427
 |  |  |  |  | 16 | 0.129 | 0.013088 | 0.139 | 0.015207 | 0.000132 | 0.000176 | 5.890
AWG22 escolhido (Secundario) |  |  |  |  | 17 | 0.115 | 0.010379 | 0.124 | 0.012164 | 0.000166 | 0.000222 | 4.671
Diâmetro do cobre | 0.064 | cm |  |  | 18 | 0.102 | 0.008231 | 0.111 | 0.009735 | 0.000209 | 0.00028 | 3.704
Área do cobre | 0.003255 | cm² |  |  | 19 | 0.091 | 0.006527 | 0.1 | 0.007794 | 0.000264 | 0.000353 | 2.937
Corrente 450A/cm² | 1.465 | A |  |  | 20 | 0.081 | 0.005176 | 0.089 | 0.006244 | 0.000333 | 0.000445 | 2.329
Resistividade do cobre a 20°C | 0.00053 | ohm/°C |  |  | 21 | 0.072 | 0.004105 | 0.08 | 0.005004 | 0.00042 | 0.000561 | 1.847
Resistividade do cobre a 100°C | 0.000708 | ohm/°C |  | Daqui para baixo | 22 | 0.064 | 0.003255 | 0.071 | 0.004013 | 0.00053 | 0.000708 | 1.465
Areá do cobre com isolamento | 0.004013 | cm² |  |  | 23 | 0.057 | 0.002582 | 0.064 | 0.003221 | 0.000668 | 0.000892 | 1.162
 |  |  |  |  | 24 | 0.051 | 0.002047 | 0.057 | 0.002586 | 0.000842 | 0.001125 | 0.921
 |  |  |  |  | 25 | 0.045 | 0.001624 | 0.051 | 0.002078 | 0.001062 | 0.001419 | 0.731
AWG28 escolhido (Terciario) |  |  |  |  | 26 | 0.04 | 0.001287 | 0.046 | 0.001671 | 0.001339 | 0.001789 | 0.579
Diâmetro do cobre | 0.029 | cm |  |  | 27 | 0.036 | 0.001021 | 0.041 | 0.001344 | 0.001689 | 0.002256 | 0.459
Área do cobre | 0.000642 | cm² |  |  | 28 | 0.032 | 0.00081 | 0.037 | 0.001083 | 0.002129 | 0.002845 | 0.364
Corrente 450A/cm² | 0.289 | A |  |  | 29 | 0.029 | 0.000642 | 0.033 | 0.000872 | 0.002685 | 0.003587 | 0.289
Resistividade do cobre a 20°C | 0.002685 | ohm/°C |  |  | 30 | 0.025 | 0.000509 | 0.03 | 0.000704 | 0.003386 | 0.004523 | 0.229
Resistividade do cobre a 100°C | 0.003587 | ohm/°C |  |  | 31 | 0.023 | 0.000404 | 0.027 | 0.000568 | 0.004269 | 0.005704 | 0.182
Areá do cobre com isolamento | 0.000872 | cm² |  |  | 32 | 0.02 | 0.00032 | 0.024 | 0.000459 | 0.005384 | 0.007192 | 0.144
 |  |  |  |  | 33 | 0.018 | 0.000254 | 0.022 | 0.000371 | 0.006789 | 0.00907 | 0.114
 |  |  |  |  | 34 | 0.016 | 0.000201 | 0.02 | 0.0003 | 0.00856 | 0.011437 | 0.091
 |  |  |  |  | 35 | 0.014 | 0.0016 | 0.018 | 0.000243 | 0.010795 | 0.014422 | 0.072
 |  |  |  |  | 36 | 0.013 | 0.000127 | 0.016 | 0.000197 | 0.013612 | 0.018186 | 0.057
 |  |  |  |  | 37 | 0.011 | 0.0001 | 0.014 | 0.00016 | 0.017165 | 0.022932 | 0.045
 |  |  |  |  | 38 | 0.01 | 8e-05 | 0.013 | 0.00013 | 0.021644 | 0.028917 | 0.036
 |  |  |  |  | 39 | 0.009 | 6.3e-05 | 0.012 | 0.000106 | 0.027293 | 0.036464 | 0.028
 |  |  |  |  | 40 | 0.008 | 5e-05 | 0.01 | 8.6e-05 | 0.034417 | 0.045981 | 0.023
 |  |  |  |  | 41 | 0.007 | 4e-05 | 0.009 | 7e-05 | 0.043399 | 0.057982 | 0.018

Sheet: Núcleo (trafo)
Parâmetro | Símbolo | Descrição | Valor [m] | Unidade
 | Ac (Ae) | Área da seção transversal do núcleo por onde passa o fluxo magnético (m²). | 0.00012 | m²
 | Wa (Aw) | Área da janela onde os enrolamentos de fio são posicionados (m²). | 8.5e-05 | m²
 | Ap (Ae.Aw) | Produto de Ac × Wa. Define a capacidade do núcleo de armazenar energia e acomodar enrolamentos (m⁴). | 1.02e-08 | m⁴
 | lc (Ie) | Comprimento médio do caminho magnético do núcleo (m). | 0.0670 | m
 | Vc (Ve) | Volume total do núcleo (m³). | 8e-06 | m³
 | MLT (lt) | Comprimento médio de uma espira (m). Utilizado no cálculo da resistência dos enrolamentos. | 0.0670 | m
 | A | Espessura do núcleo | 0.72 | cm
 | B | Comprimento do núcleo | 1.46 | cm
 | C | Espessura da janela | 0.455 | cm
 | D | Comprimento da janela | 1.80 | cm
Parâmetro calculado
Ae.Aw | 0.1157 | m⁴
 |  |  |  |  | https://www.thornton.com.br/produtos/nee.htm
Escolhido E-30/7 |  |  |  | Núcleo | Ae [cm²] | Aw [cm²] | Ie [cm] | It [cm] | Ve [cm³] | AeAw [cm⁴]
Ae | 1.2 | cm² |  | E-20 | 0.312 | 0.26 | 4.28 | 3.8 | 1.34 | 0.08
Aw | 0.85 | cm² |  | E-30/7 | 0.6 | 0.8 | 6.7 | 5.6 | 4 | 0.48
le | 6.7 | cm² |  | E-30/14 | 1.2 | 0.85 | 6.7 | 6.7 | 8 | 1.02
lt | 6.7 | cm |  | E-42/15 | 1.81 | 1.57 | 9.7 | 8.7 | 17.1 | 2.84
Ve | 8 | cm³ |  | E-42/20 | 2.4 | 1.57 | 9.7 | 10.5 | 23.3 | 3.77
Ae.Aw | 1.02 | cm⁴ |  | E-55 | 3.54 | 2.5 | 11.2 | 11.6 | 42.5 | 8.85
 |  |  | 6.82

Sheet: Projeto do transformador
Dado | Descrição | Valor | Arredondamento | Unidade | Equação | Tipo
Δ |  | 0.034 |  | cm | 7,5/sqrt(fs) | Calculado
Dfio | Calculo da seção do fio e do número de fios em paralelo | 0.067 |  | cm | 2*Δ | Calculado | AWG max=22
Kw | Fator de ocupação | 0.8 |  |  |  | Escolhido
Kp | Fator de ocupação do primário | 0.6 |  |  |  | Típico
Pt |  | 50 |  |  |  | Dado
Bmax |  | 0.3 |  |  |  | Típico
fs |  | 50000 |  |  |  | Dado
Jmax |  | 600 |  |  |  | Escolhido
Iprimpico |  | 3.1 |  |  |  | Medido
Vpeficaz |  | 71.25 |  |  |  | Medido
n | Relação do número de espiras | 2 |  |  |  | Dado
Iprimeficaz |  | 1.3 |  |  |  | Medido
Ae.Aw | Área Transversal do núcleo vezes da janela | 0.1157 |  |  | (D*Vin)/(Np*) | Calculado
Ae | Área da seção transversal do núcleo | 1.2 |  | cm² | Ae | Tabelado
Aw | Área da seção transversal da janela | 0.85 |  | cm² | Aw | Tabelado
Lme |  | 6.7 |  | cm | lt | Tabelado
A | Espessura do núcleo | 0.72 |  | cm |  | Tabelado
B | Comprimento do núcleo | 0.73 |  | cm |  | Tabelado
C | Espessura da janela | 0.490 |  | cm | ((25-15,9)/2)*10^-1 | Tabelado
D | Comprimento da janela | 1.81 |  | cm |  | Tabelado
Ve | Volume do núcleo | 8.00 |  | cm³ |  | Tabelado
lespira | Comprimento médio de uma espira | 6.7 |  | cm |  | Tabelado
Primário
Np | Número de espiras primário | 49.48 | 49 | voltas | (Vp*10^4)/(4*Bmax*Ae) | Calculado | AWG=23
SL | Área da bitola do condutor | 0.002166666667 |  | cm² | ILeficaz/Jmax | Calculado
Scu | Área do cobre cujo o diâmetro máximo é limitado por Dfio | 0.002582 |  | cm² |  | Escolhido
Scui | Área do cobre com isolamento | 0.003221 |  | cm² |  | Escolhido
pfio | Resistividade do fio | 0.000668 |  | ohms/°C |  | Escolhido
ncond | Número de condutores em paralelo | 0.839 | 1 |  | SL/Scu | Calculado
Awmin |  | 0.1973 |  |  | (N*ncond*ScuI)/(Kw) | Calculado
Exec | Possibilidade de execução | 0.2321 |  |  | Awmin/Aw | Calculado
 | Tamanho do chicote | 4.3
Secundário
Iseceficaz |  | 1.3 |  |  |  |  | AWG=22
Ns | Número de espiras secundário | 24.7 | 25 | voltas | Nsec/n | Calculado
SL | Área da bitola do condutor | 0.002166666667 |  | cm² | ILeficaz/Jmax | Calculado
Scu | Área do cobre cujo o diâmetro máximo é limitado por Dfio | 0.003255 |  | cm² |  | Escolhido
Scui | Área do cobre com isolamento | 0.004013 |  | cm² |  | Escolhido
pfio | Resistividade do fio | 0.000668 |  | ohms/°C |  | Escolhido |  | Ponto Roxo | Primario
ncond | Número de condutores em paralelo | 0.666 | 1 |  | SL/Scu | Calculado |  | Ponto Laranja | Secundario
Awmin |  | 0.1254 |  |  | (N*ncond*ScuI)/(Kw) | Calculado
Exec | Possibilidade de execução | 0.1475 |  |  | Awmin/Aw | Calculado
 | Tamanho do chicote | 2.7
Terciário
Itereficaz |  | 0.4 |  |  |  |  | AWG=28
Nt | Número de espiras terciário | 49.5 | 49 | voltas | Np | Calculado | Seleionar fio diferente para os enrolamentos
SL | Área da bitola do condutor | 0.00059 |  | cm² | ILeficaz/Jmax | Calculado
Scu | Área do cobre cujo o diâmetro máximo é limitado por Dfio | 0.000642 |  | cm² |  | Escolhido
Scui | Área do cobre com isolamento | 0.000872 |  | cm² |  | Escolhido
pfio | Resistividade do fio | 0.000668 |  | ohms/°C |  | Escolhido
ncond | Número de condutores em paralelo | 0.919 | 1 |  | SL/Scu | Calculado
Awmin |  | 0.0534 |  |  | (N*ncond*ScuI)/(Kw) | Calculado
Exec | Possibilidade de execução | 0.0628 |  |  | Awmin/Aw | Calculado
 | Tamanho do chicote | 4.3
P | Perdas | 0.6 |  |  |  | Calculado
 | Possibilidade de execução total | 0.4
 | ponto do primario | Vcc
 | Saida do primario | entrada da chave
 | Ponto do secundario | Entrada dp diodo 1
 | Saisda do secundario | entrada do diodo 2
 | Ponto do terciario | Saida do diodo 3
 | Saida do teciario | Vcc

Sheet: Componentes
CAPACITOR |  |  |  |  |  |  | DIODOS |  |  |  |  |  |  |  |  |  | INTERRUPTOR
Dado | Descrição | Valor | Unidade |  |  |  | Dado | Valor | Unidade |  |  |  |  |  |  |  | Dado | Valor | Unidade
C | Capacitância | 4.7e-05 | F |  |  |  | ID1med | 0.979 | A |  |  |  |  |  |  |  | ISmed | 0.65 | A
fs | Frequência de comutação | 50000 | Hz |  |  |  | ID1eficaz | 1.98 | A |  |  |  |  |  |  |  | ISeficaz | 1.31 | A
Iceficaz |  | 3.96 | A |  |  |  | VD1max | 2.47e-06 | V |  |  |  |  |  |  |  | ISmax | 3.34 | A
 |  |  |  |  |  |  |  |  |  |  |  |  |  |  |  |  | VSmed | 9974 | V
Icmax |  | 0.16 |  |  |  |  | ID2med | 2.97 | A |  |  |  |  |  |  |  | VSeficaz | 12.21 | V
Icmed |  | -0.0014 |  |  |  |  | ID2eficaz | 3.43 | A |  |  |  |  |  |  |  | VSmax | 200 | V
VCeficaz |  | 12.37 | V |  |  |  | VD2max | 7.4e-06 | V
VCmax |  | 12.38 | V |  |  |  |  |  |  |  |  |  |  |  | Modelos | Vdsmáx | Idmáx | PD máx | Tj | Tstg | Datasheet
VCmed |  | 12.37 | V |  |  |  | ID3med | 0.154 |  |  |  |  |  |  | IRF740 | 400V | 10A | 125W | -55 to +150 | -55 to +150 | https://www.vishay.com/docs/91054/91054.pdf
 |  |  |  |  |  |  | ID3eficaz | 0.355 | A |  |  |  |  |  | IRF630 | 200V | 9A | 74W | 150°C | -65~150 | https://www.vishay.com/docs/91031/irf630.pdf
 |  |  |  |  |  |  | VD3max | 5.37e-06 | A |  |  |  |  |  | IRF710 | 400V | 2A | 36W | -55 to +150 | -55 to +150 | https://www.vishay.com/docs/91041/91041.pdf
Modelos | Vc | Ic | Datasheet |  |  |  |  |  |  |  | dissipador |  |  |  | IRFP4768PbF | 250V | 66A | 520W | -55 to +150 | -55 to +175 | https://www.infineon.com/dgdl/irfp4768pbf.pdf?fileId=5546d462533600a40153562c959b2021
Siemens B85042 (Laranja) | 50V |  |  | Modelos | VR | IF(AV) | Tj máx | Tstg | Rthjc | Rthcd | Rthda | Datasheet | Datasheet
Azul |  |  |  | MUR810 | 100V | 8A | −65 to +175 | −65 to +175 | 3 |  |  | https://www.alldatasheet.com/html-pdf/92131/ONSEMI/MUR810/550/3/MUR810.html | https://datasheet.octopart.com/MUR810G-ON-Semiconductor-datasheet-9765928.pdf
Preto1 | 400V |  |  | MUR820 | 200V | 8A | −65 to +175 | −65 to +175 | 3 |  |  | https://datasheet.octopart.com/MUR810G-ON-Semiconductor-datasheet-9765928.pdf |  |  | Modelos | Rds | IDSeficaz | alfaRd | Pcon [W]
Preto2 | 250V |  |  | MUR830 | 300V | 8A | −65 to +175 | −65 to +175 | 2 |  |  | https://datasheet.octopart.com/MUR830-Inchange-Semiconductor-datasheet-15981735.pdf |  |  | IRF740 | 0.55 | 1.31 | 2.375 | 2.24
 |  |  |  | MUR840 | 400V | 8A | −65 to +175 | −65 to +175 | 2 |  |  | https://datasheet.octopart.com/MUR810G-ON-Semiconductor-datasheet-9765928.pdf |  |  | IRF630 | 0.4 | 1.31 | 2.25 | 1.54449
 |  |  |  | MUR880 | 800V | 8A | −65 to +175 | −65 to +175 |  |  |  | https://www.alldatasheet.com/datasheet-pdf/download/577473/DIGITRON/MUR880.html |  |  | IRF710 | 3.6 | 1.31 | 2.625 | 16.217145
 |  |  |  |  |  |  |  |  |  |  |  |  |  |  | IRFP4768PbF | 0.0175 | 1.31 | 3.375 | 0.10
 |  |  |  | Modelos | x | y | Rd [ohm] | VTo [V] | PD1 [W] | PD2 [W] | PD3 [W] | TjD1 | TjD2 | TjD3 | Modelos | VSmax | ISmax | tr | Woff | tf MOS | trr Diodo | Qrr Diodo | Won | fs | Pcom
 |  |  |  | MUR810 | 0.65 | 3.43 | 5.27 | 0.895 | 21.53 | 64.65 | 0.80 | 89.60 | 218.95 | 27.41 | IRF740 | 200 | 3.34 | 2.7e-08 | 1.8036e-05 | 2.4e-08 | 7.9e-07 | 8.2e-06 | 0.00164 | 1000000 | 1658.036013
 |  |  |  | MUR820 | 0.65 | 3.43 | 5.27 | 0.895 | 21.53 | 64.65 | 0.80 | 89.60 | 218.95 | 27.41 | IRF630 | 200 | 3.34 | 2.8e-08 | 1.8704e-05 | 2e-08 | 3.4e-07 | 2.2e-09 | 0.00000044 | 1000000 | 19.14400454
 |  |  |  | MUR830 | 0.65 | 2.40 | 3.68 | 1.30 | 15.72 | 47.21 | 0.66 | 56.43 | 119.41 | 26.33 | IRF710 | 200 | 3.34 | 9.9e-09 | 6.6132e-06 | 1.1e-08 | 5.4e-07 | 1.6e-06 | 0.00032 | 1000000 | 326.613204
 |  |  |  | MUR840 | 0.65 | 2.40 | 3.68 | 1.30 | 15.72 | 47.21 | 0.66 | 56.43 | 119.41 | 26.33 | IRFP4768PbF | 200 | 3.34 | 1.6e-07 | 0.00010688 | 1.1e-07 | 2e-07 | 2.26e-06 | 0.00045 | 1000000 | 558.8800147
 |  |  |  | MUR880 |  |  |  |  | 0.00 | 0.00 | 0.00 | 25.00 | 25.00 | 25.00
 |  |  |  |  |  |  |  |  | VTo*IDmed + Rd*IDef^2 |  |  | Tamb+PD*(Rthjc+Rthcd+Rthda) |  |  | Modelos | Ptot
 |  |  |  |  |  |  |  |  |  |  |  |  |  |  | IRF740 | 1660.28
 |  |  |  |  |  |  |  |  |  |  |  |  |  |  | IRF630 | 20.68849454
 |  |  |  |  |  |  |  |  |  |  |  |  |  |  | IRF710 | 342.830349
 |  |  |  |  |  |  |  |  |  |  |  |  |  |  | IRFP4768PbF | 558.9813719

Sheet: Circuito de Comando
 | Dado | Valor | Unidade
UC3525 | fs | 50000
 | CT | 1e-08 | 5e-09 | 2e-09 | 1e-09
 | RT | 2857.2 | 5714.4 | 14286 | 28572
 | Vportmax | 2.9 | V
 | Vportmin | 0.86 | V
 | ICss | 5e-05 | A
 | D | 0.5 | razao cíclica
 | Vref | 5.1 | V
IRF740 | VDS | 400 | V
 | RDS | 0.55 | ohm
 | ID | 10 | A
 | tf | 2.4e-08 | s
 | tr | 2.7e-08 | s
 | CISS | 1.5e-09 | F
 | tstart | 0.04
 | Css | 3.921568627e-07
 | VC | 1.88
 | R3 | 10000 | ohm
 | RTOT | 27127.65957 | ohm
 | R1 | 17127.65957 | ohm
 | RG | 7.3 | ohm

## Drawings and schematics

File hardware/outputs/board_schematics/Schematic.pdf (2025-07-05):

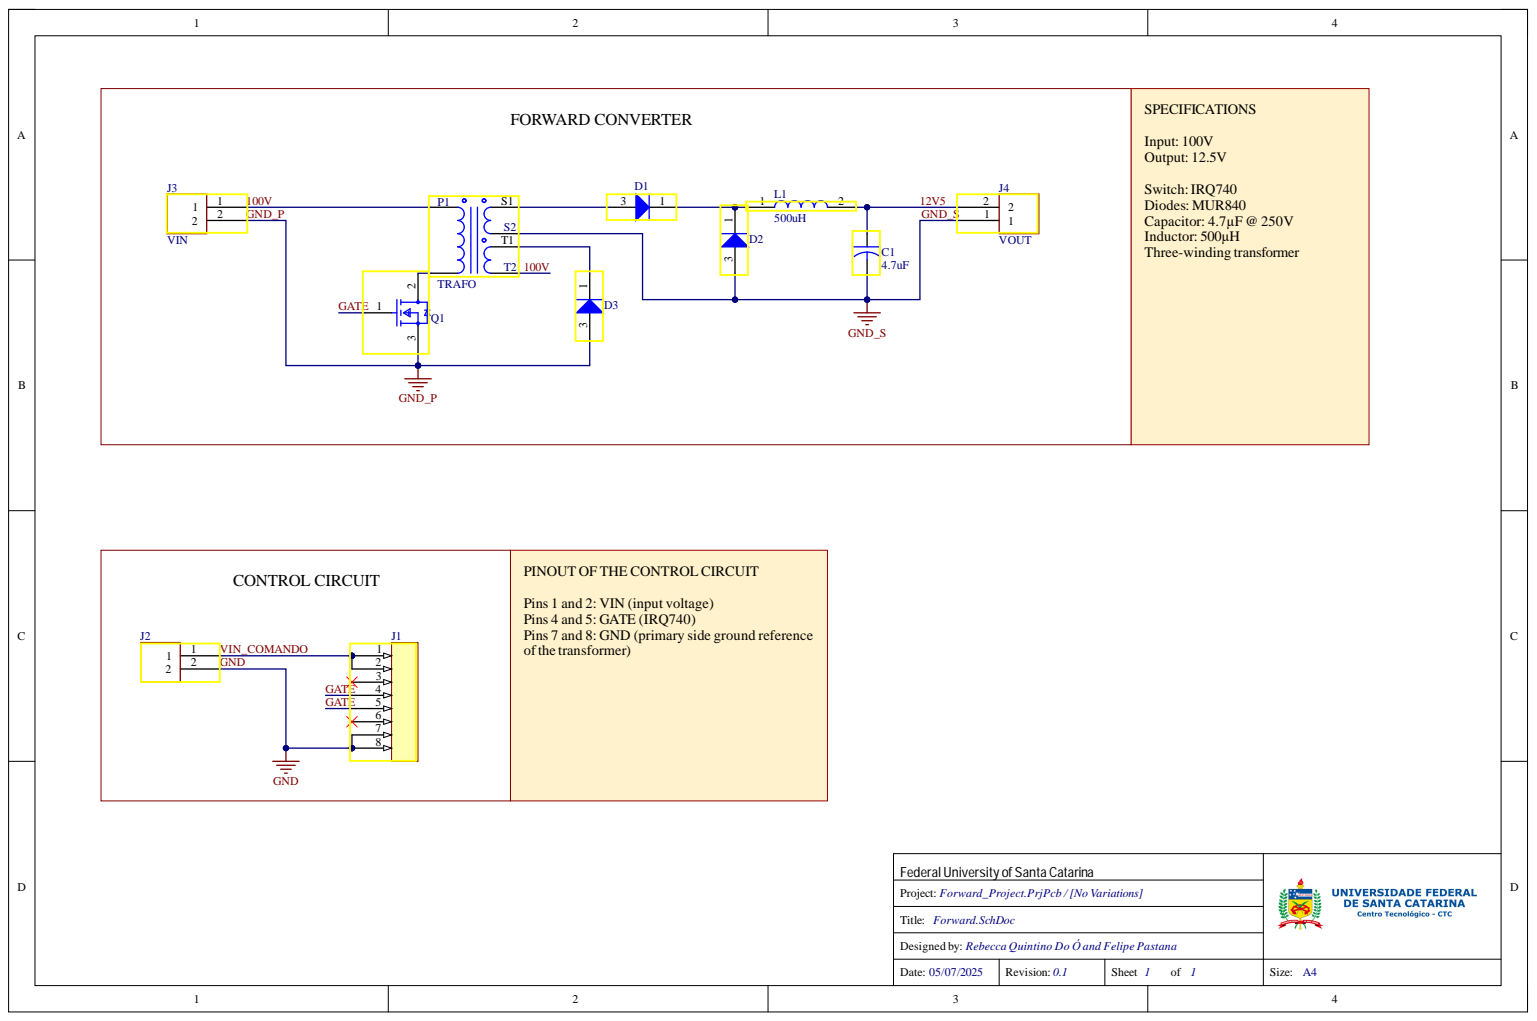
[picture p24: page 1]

PINOUT OF THE CONTROL CIRCUIT

Pins 1 and 2: VIN (input voltage)
Pins 4 and 5: GATE (IRQ740)
Pins 7 and 8: GND (primary side ground reference
of the transformer)

Federal University of Santa Catarina

Rebecca Quintino Do Ó and Felipe Pastana

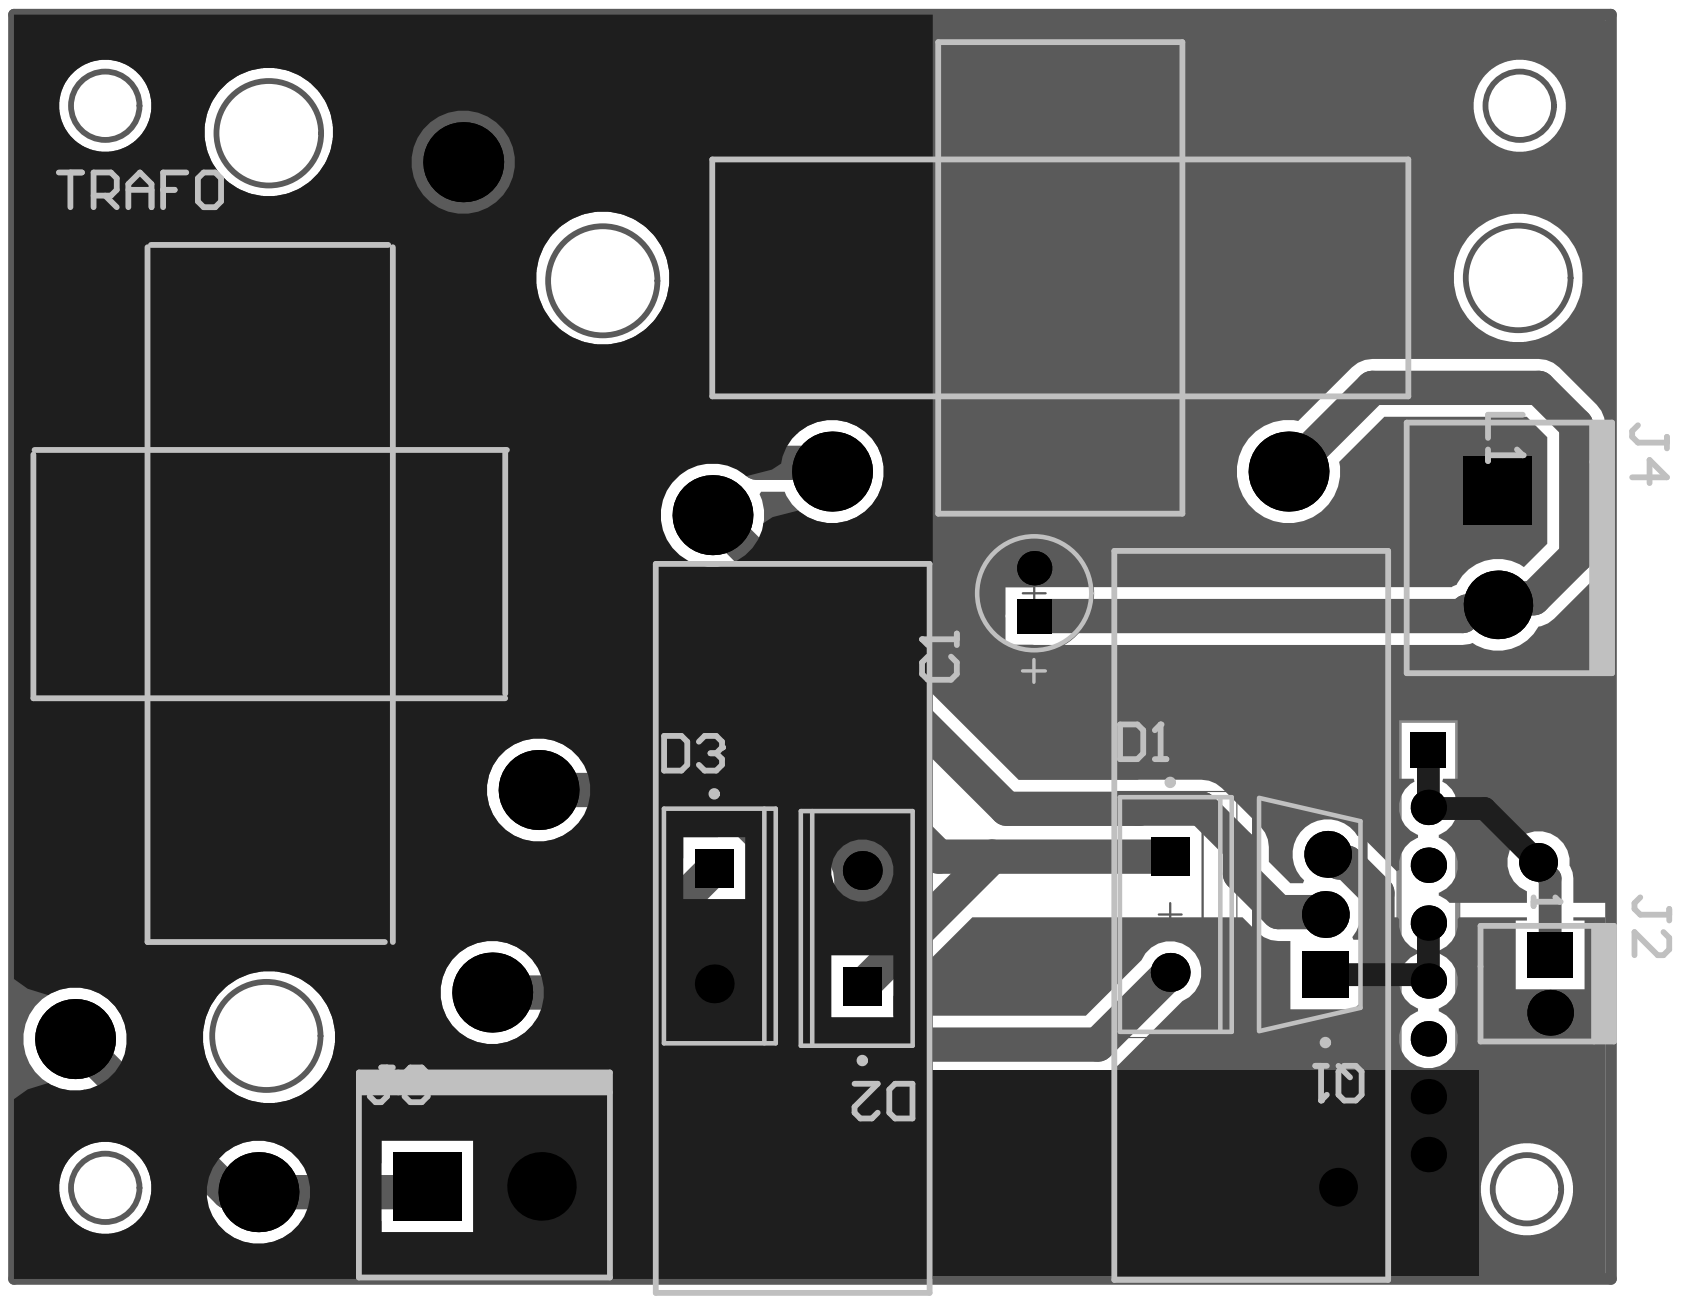
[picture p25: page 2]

Line # | Designator | Name | Description | Quantity | Manufacturer 1 | Manufacturer Part Number 1 | Manufacturer Lifecycle 1 | Supplier 1 | Supplier Part Number 1 | Supplier Unit Price 1 | Supplier Subtotal 1
| C1 | 4.7uF | Electrolytic capacitor | 1
| D1, D2, D3 | MUR840G | DIODE STANDARD 400V 8A TO2202 | 3
| J1 | header 8pin | Header 8pin | 1
| J2 | Con_Molex_2_pin | Connector KK Male 180° 2 Pins | 1
| J3 | VIN | Connector Borne KRE 2 Vias | 1
| J4 | VOUT | Connector Borne KRE 2 Vias | 1
| L1 | 500uH | Indutor manufacture handmade | 1
| Q1 | IRF740 | MOSFET N-CH 400V 10A TO220AB | 1
| TRAFO | Three-winding transformer | Handmade three-winding transformer | 1

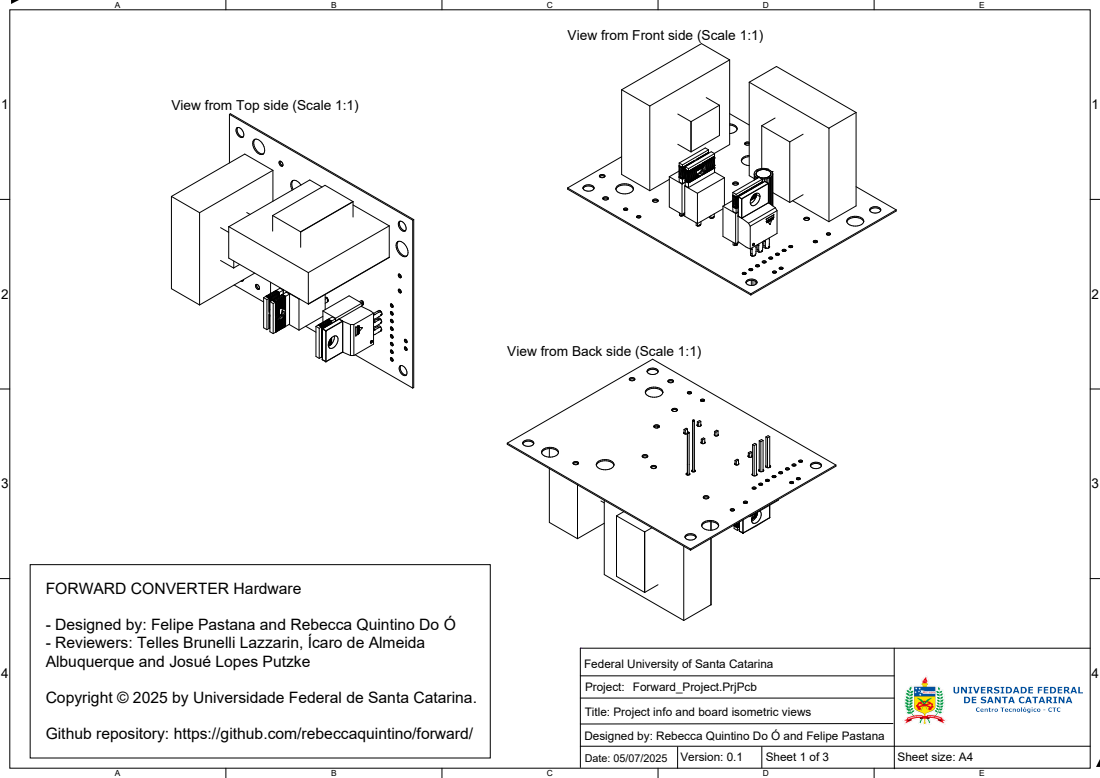
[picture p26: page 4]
Date: 05/07/2025 Version: 0.1; Sheet 1 of 3; Sheet size: A4; Forward_Project.PrjPcb

View from Front side (Scale 1:1)

View from Top side (Scale 1:1)

View from Back side (Scale 1:1)

FORWARD CONVERTER Hardware

- Designed by: Felipe Pastana and Rebecca Quintino Do Ó
- Reviewers: Telles Brunelli Lazzarin, Ícaro de Almeida
Albuquerque and Josué Lopes Putzke
Copyright © 2025 by Universidade Federal de Santa Catarina.

Federal University of Santa Catarina
Project:
Title: Project info and board isometric views
Designed by: Rebecca Quintino Do Ó and Felipe Pastana

Github repository: https://github.com/rebeccaquintino/forward/

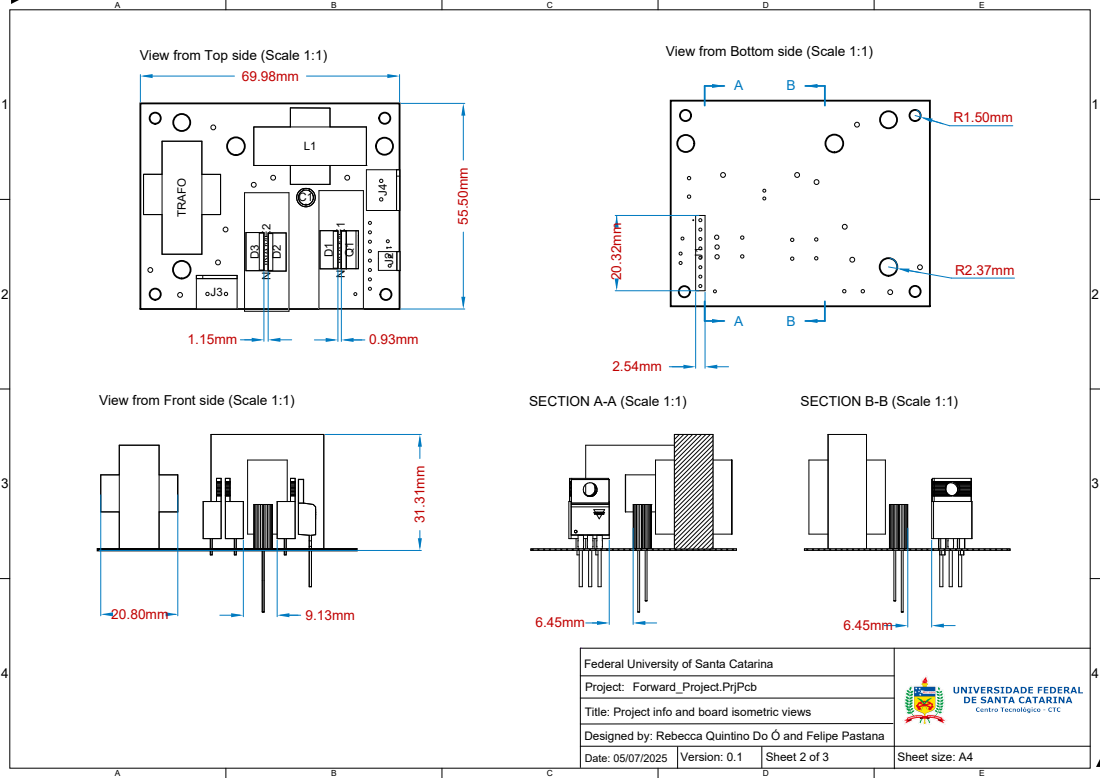
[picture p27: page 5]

View from Bottom side (Scale 1:1)

View from Top side (Scale 1:1)

View from Front side (Scale 1:1)

Federal University of Santa Catarina
Project:
Title: Project info and board isometric views

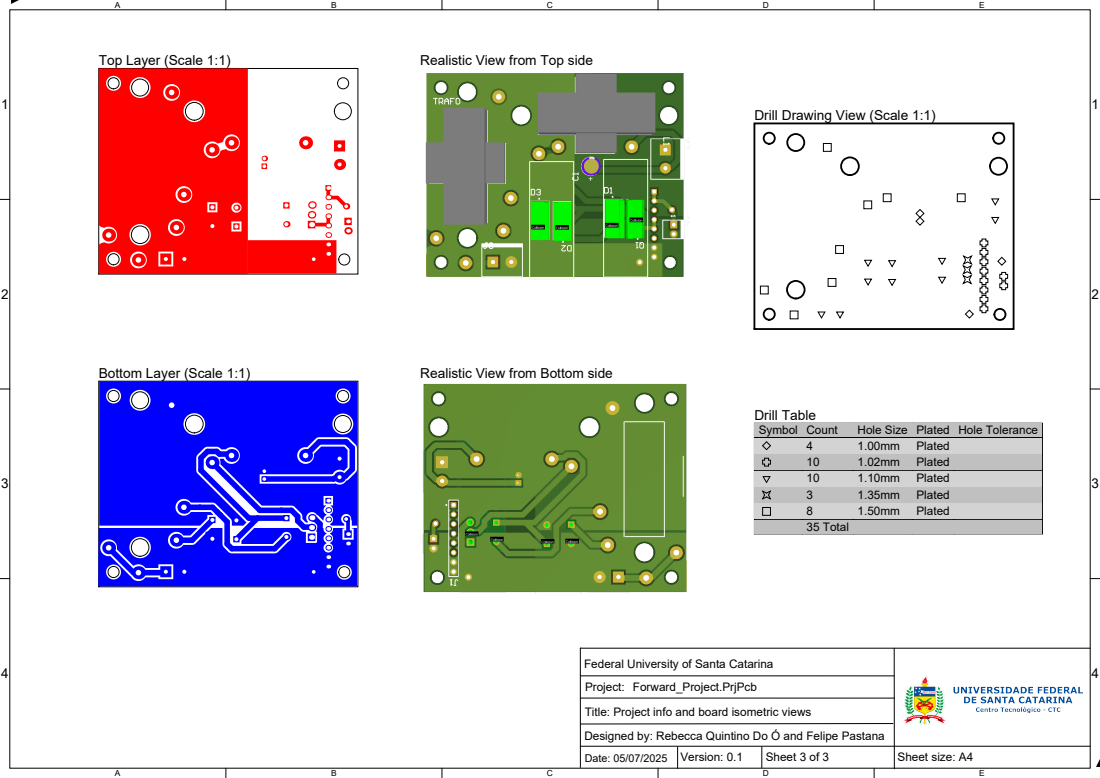
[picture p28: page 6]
Date: 05/07/2025; Version: 0.1; Sheet 3 of 3; Sheet size: A4; Forward_Project.PrjPcb; Drill Table

Top Layer (Scale 1:1)

Realistic View from Top side

Drill Drawing View (Scale 1:1)

Bottom Layer (Scale 1:1)

Realistic View from Bottom side

Symbol | Count | Hole Size | Plated | Hole Tolerance

4 | 1.00mm | Plated
10 | 1.02mm | Plated
10 | 1.10mm | Plated
3 | 1.35mm | Plated
8 | 1.50mm | Plated
35 Total

Federal University of Santa Catarina
Project:
Title: Project info and board isometric views

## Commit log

2025-06-12 hardware: Created the Altium Project
    [Forward.SchDoc, Forward_Project.PrjPcb]
2025-06-12 hardware: added some components
    [Forward.SchDoc, Forward_Project.PrjPcb]
2025-06-12 Adição do header 1X8
    [Forward.SchDoc]
2025-06-13 Adição footprint do indutor
    [Forward.SchDoc, Forward_Project.PrjPcb]
2025-06-13 Atualização modelo do indutor
    [Forward.SchDoc]
2025-06-13 hardware: added trafo schematic and footprint
2025-06-13 Adicionado footprint da chave na biblioteca
    [Forward.SchDoc]
2025-06-13 hardware:Forward_Project - Updated schematic
    [Forward.SchDoc, Forward_Project.PrjPcb]
2025-06-13 Primeiro layout PCB
    [Forward.SchDoc, PCB1.PcbDoc]
2025-06-13 hardware:Forward_Project - added V1.0 of PCB on project
    [Forward.PcbDoc]
2025-06-28 Revision 0.1
    [Forward.PcbDoc, Forward.SchDoc, Forward_Project.PrjPcb]
2025-06-30 hardware: Layout modified
    [Forward.PcbDoc]
2025-06-30 harware: Add gerber files
    [Forward.GBL, Forward.GKO, Forward.GTL]
2025-06-30 Fabrication Outputs: Update Gerber files
    [Forward_Project.PrjPcb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]
2025-07-05 Add documentation
    [Forward.PcbDoc, Forward.SchDoc, Forward_Project.PrjPcb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]
